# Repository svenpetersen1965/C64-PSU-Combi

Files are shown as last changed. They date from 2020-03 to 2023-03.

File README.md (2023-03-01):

# C64-PSU-Combi
A PSU for the Commodore C64 and up to two 1541-II floppy disk drives. It is based on a transformer 
for the 9VAC, which is required in a C64 and a (PCB) external power supply module, which provides
the +5V and +12V for the C64 and the 1541-II floppy disk drives. Depending on the used power supply
module, one of the 1541-II connectors can be replaced with an Amiga connection, which also requires 
-12V. This option has not been tested, since I don't have an Amiga. The PSU combi should be strong 
enough.

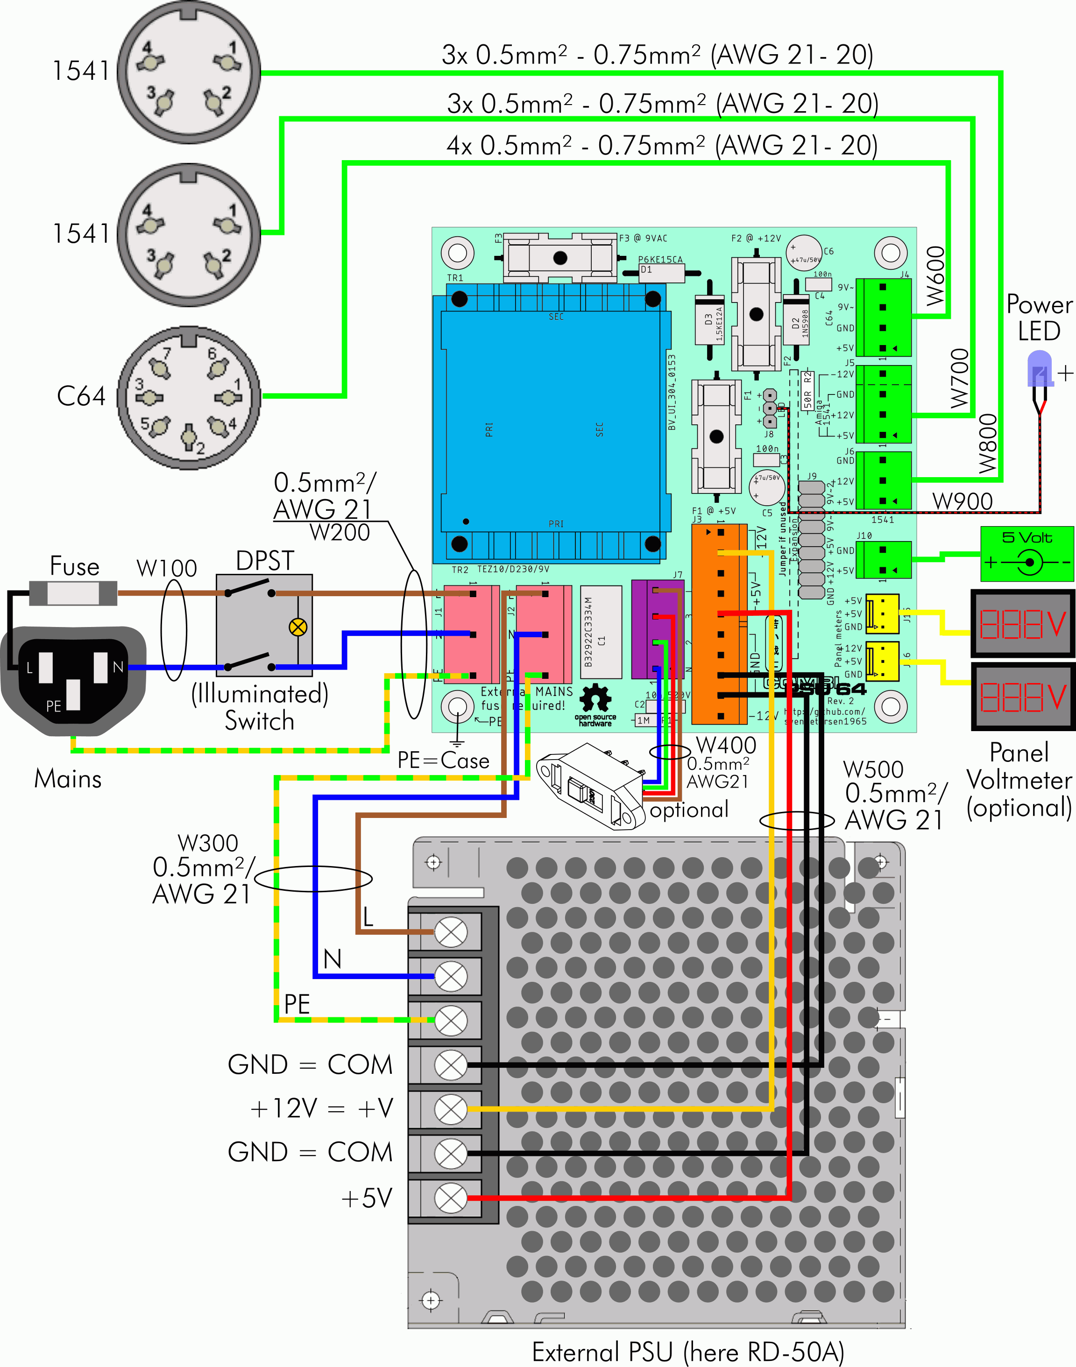
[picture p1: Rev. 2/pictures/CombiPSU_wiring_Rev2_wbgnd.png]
Block Diagram


This build is for the more experienced, since power supplies can be hazzardous and the involved 
mains voltage is potentially lethal.

Find some info on the required cable making <a href="http://tech.guitarsite.de/cable_making.html">on my website</a>

The power supply has  an open concept and can be configured to taste. It should be planned before 
parts are purchased.

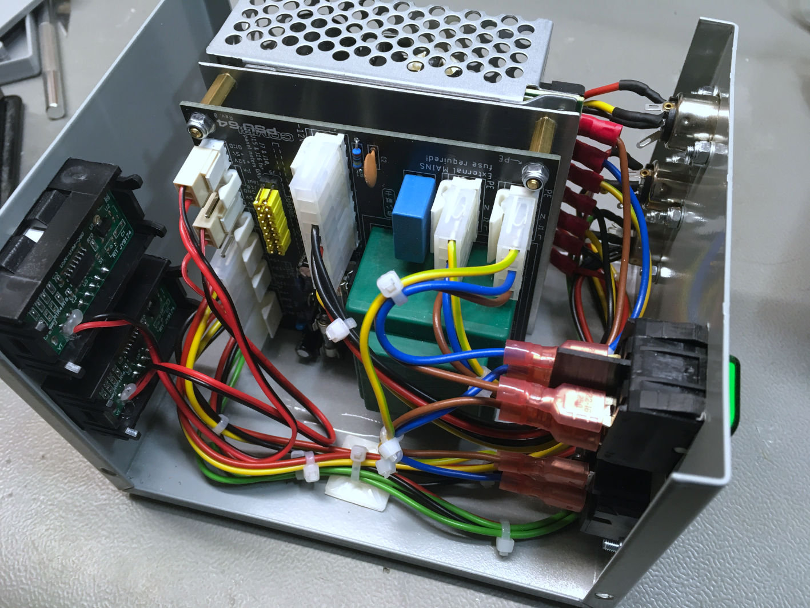
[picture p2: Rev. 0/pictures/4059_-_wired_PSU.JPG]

C64 PSU Combi in a Hammond 1411P case

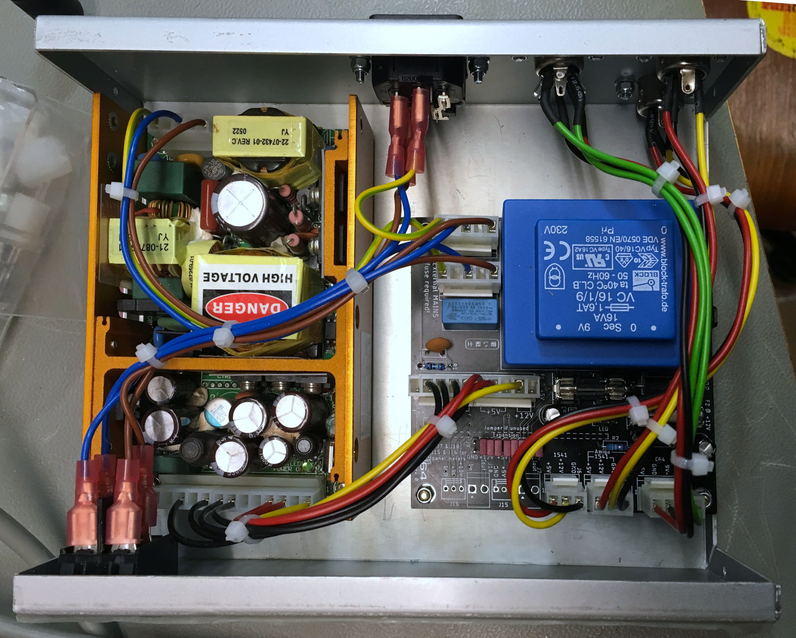
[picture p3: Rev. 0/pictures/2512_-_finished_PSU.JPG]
Finished!

C64 PSU Combi in a Teko 384 case

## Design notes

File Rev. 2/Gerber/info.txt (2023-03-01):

       
       Board: C64_PSU_Combi
       Rev.:  2
  
       Files:
       ======
  
       All Gerber files are generated in extended gerber format (RS274X)
       *.TOP        : Film top copper
       *.BOT        :  -"- bottom copper
       *.STC        :  -"- top soldermask 
       *.STS        :  -"- bottom soldermask
       *.PLC        :  -"- silk screen top
       *.PLS        :  -"- silk screen bottom
       *.DK         : Drills plated Through (Excellon)
       *.NDK        : Drills not plated Through (Excellon)
       *.OUT        : Board outline

       Board Size:
       ===========
       Length     :   98.0 mm
       Width      :   94.0 mm
       Thickness  :   1.6 mm
       Material   :   FR 4
       Copper     :   35 um
       Surface    :   HASL
       
       Remarks:
       ========
       Width >= 6mil
       Distance >= 6mil
       Drill >= 0.35mm

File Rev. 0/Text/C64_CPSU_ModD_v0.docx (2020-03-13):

C64 Combi PSU Rev. 0

Module Description

# Introduction

The C64 combi PSU is a power supply board for the Commodore C64 and up to two floppy disk drives 1541-II. Depending on the used external DC-power supply, one of the 1541 connectors can be used for a Commodore AMIGA.

This board connects to mains and it contains a 9V transformer, which provides the 9VAC for the C64. For the DC-Voltages, a variety of power supply modules can be connected externally.

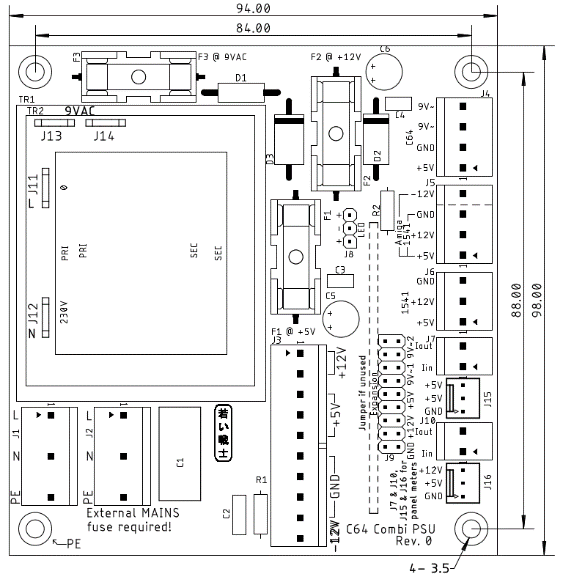
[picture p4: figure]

Figure 1: Measures of the board

The board allows a number of alternative placements and optional components:

- There are footprints for two different transformers, a chassis mount transformer can be connected via four spade connectors
- Two panel meters for +5V and +12V can be connected, if not wanted, the connectors do not need to be populated.
- An extension module can be connected, which can measure or control the output voltages
- One connector can provide voltages for either a 1541-II disk drive or an Amiga

# External Power Supply

The external power supply should either have the output voltages +5V (≥3.5A), +12 V (≥1A) for one C64 and two 1541-II floppy disk drives or +5V (≥5A), +12V (≥2A), -12V (≥0.1A). The traces on the PCB are calculated for 4A (+12V, 9VAC), 6A (+5V) and 2.5A (-12V). The fuses have to be picked according to the maximum current of the output voltages and the copper traces.

For best operation (due to voltage drops on the PBC and the cables), it is recommended to adjust the power supply to +5.1V to +5.2V. While adjustment, any devices must not be connected to the PSU. The other voltages need to be checked. A slightly higher output on +12V is also ok.

Suggested PSUs (many other possible):

- Mean Well: RD-50A (+5V @ 6A, +12V @ 2A) (e.g. Mouser: €15.34)
- Mean Well: RT-65B (+5V @ 5A, +12V @ 2.8A, -12V @ 0.5A) (e.g. Mouser: 17,43€)

# The Expansion Module

For monitoring or controlling the output voltages of the PolyPower64, an optional Expansion module can be connected to J19. The connector has input and output pins for the 9VAC, the +12V and the +5V. It also offers two GND pins.

In case the Expansion Module is not installed, the pins, mentioned before, have to be bridged with jumpers (rated 3A).

A maximum height of 20mm is assumed for the expansion module.

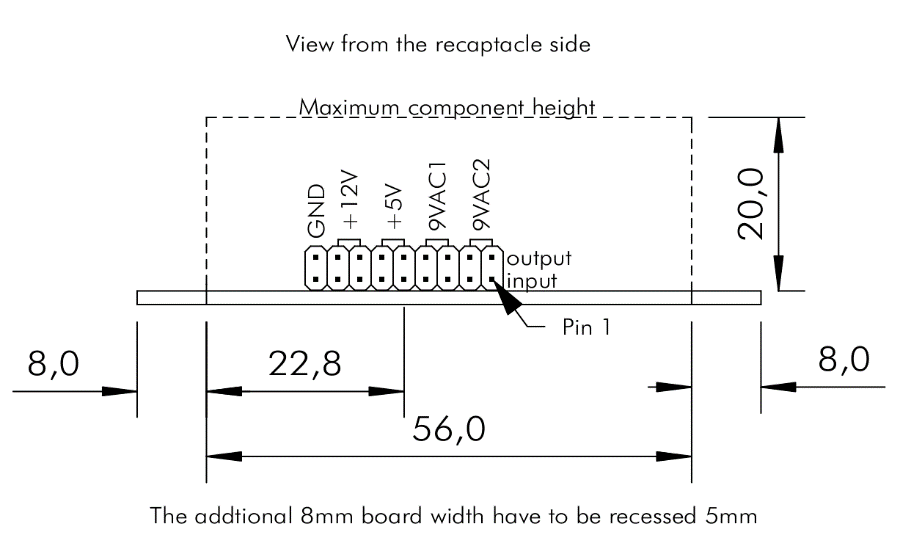
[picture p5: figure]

Figure 2: Dimensions of the Expansion Module

The maximum dimensions of the Expansion Module are shown in Figure 2. The length of the module depends on the enclosure of the power supply and the standoffs for the PCB.

Any voltage, that is unused on the expansion module should be bridged (40mil trace!) on there. The same is valid for voltages, which do not have a current measurement or any switch like function.

To prevent slipping of the connectors, the Expansion Module needs to be secured with silicon glue (which is reversible) after testing.

# Connectors

## J1, J2 – Mains connectors

- Molex KK 396 Header, Vertical, Friction Lock, 5 Circuits, Tin (Sn) Plating (Pin 2 and pin 4 removed): P/N 0026604050
- KK 3.96mm Crimp Terminal Housing, Friction Ramp, 5 Circuits, Natural: P/N 09503051
- KK 396 Crimp Terminal 2478, 18-24 AWG, Bag, Brass Tin (Sn): P/N 08500106.

Pin | Signal
1 | L (hot)
3 | N (neutral)
5 | PE (protective earth)

J1 is for the mains input, J2 is branching to the external DC-PSU.

## J3 – DC-PSU

- Molex KK 396 Header, Vertical, Friction Lock, 10 Circuits, Tin (Sn) Plating: P/N 0026604100
- KK 3.96mm Crimp Terminal Housing, Friction Ramp, 10 Circuits, Natural: P/N 09503101
- KK 396 Crimp Terminal 2478, 18-24 AWG, Bag, Brass Tin (Sn): P/N 08500106.

Pin | Signal
1 | +12V
2 | +12V
3 | +5V
4 | +5V
5 | +5V
6 | GND
7 | GND
8 | GND
9 | GND
10 | -12V

## J4 – C64 Output

- Molex KK 396 Header, Vertical, Friction Lock, 4 Circuits, Tin (Sn) Plating: P/N 0026604040
- KK 3.96mm Crimp Terminal Housing, Friction Ramp, 4 Circuits, Natural: P/N 09503041
- KK 396 Crimp Terminal 2478, 18-24 AWG, Bag, Brass Tin (Sn): P/N 08500106.

Pin | Signal
1 | +5V
2 | GND
3 | 9VAC2
4 | 9VAC1

## J5 – 1541-II or Amiga Output

### Version 1541-II

For the 1541-II only populate Pin 1-3. See J6.

### Version Amiga

- Molex KK 396 Header, Vertical, Friction Lock, 4 Circuits, Tin (Sn) Plating: P/N 0026604040
- KK 3.96mm Crimp Terminal Housing, Friction Ramp, 4 Circuits, Natural: P/N 09503041
- KK 396 Crimp Terminal 2478, 18-24 AWG, Bag, Brass Tin (Sn): P/N 08500106.

Pin | Signal
1 | +5V
2 | +12V
3 | GND
4 | -12V

## J6 – 1541-II Output

- Molex KK 396 Header, Vertical, Friction Lock, 3 Circuits, Tin (Sn) Plating: P/N 0026604030
- KK 3.96mm Crimp Terminal Housing, Friction Ramp, 3 Circuits, Natural: P/N 09503031
- KK 396 Crimp Terminal 2478, 18-24 AWG, Bag, Brass Tin (Sn): P/N 08500106.

Pin | Signal
1 | +5V
2 | +12V
3 | GND

## J7, J15 – Panel Meter (+5V)

### ~~J7 – Current path~~

The current measurement is not functional with any known Panel Meters. It will be dropped in future revisions.

- Molex KK 396 Header, Vertical, Friction Lock, 2 Circuits, Tin (Sn) Plating: P/N 0026604020
- KK 3.96mm Crimp Terminal Housing, Friction Ramp, 2 Circuits, Natural: P/N 09503021
- KK 396 Crimp Terminal 2478, 18-24 AWG, Bag, Brass Tin (Sn): P/N 08500106.

Pin | Signal
1 | Current in (+)
2 | Current out (-)

### J15 – Voltage connection

- Molex KK 254 Wire-to-Board Header, Vertical, with Friction Lock, 3 Circuits, Tin (Sn) Plating: P/N 22272031
- KK 254 Crimp Housing, 3 Circuits, Natural: P/N 22-01-3037
- KK 254 Crimp Terminal, 22-30 AWG, Bag, Hot Tin (Sn) Dip Plating: P/N 08500114

Pin | Signal
1 | GND
2 | +5V (supply)
3 | +5V (measurement)

## J10, J16 – Panel Meter (+12V)

### ~~J~~~~10~~ ~~– Current path~~

The current measurement is not functional with any known Panel Meters. It will be dropped in future revisions.

- Molex KK 396 Header, Vertical, Friction Lock, 2 Circuits, Tin (Sn) Plating: P/N 0026604020
- KK 3.96mm Crimp Terminal Housing, Friction Ramp, 2 Circuits, Natural: P/N 09503021
- KK 396 Crimp Terminal 2478, 18-24 AWG, Bag, Brass Tin (Sn): P/N 08500106.

Pin | Signal
1 | Current in (+)
2 | Current out (-)

### J16 – Voltage connection

- Molex KK 254 Wire-to-Board Header, Vertical, with Friction Lock, 3 Circuits, Tin (Sn) Plating: P/N 22272031
- KK 254 Crimp Housing, 3 Circuits, Natural: P/N 22012031
- KK 254 Crimp Terminal, 22-30 AWG, Bag, Hot Tin (Sn) Dip Plating: P/N 08500114

Pin | Signal
1 | GND
2 | +5V (supply)
3 | +12V (measurement)

## J11-J14 – Chassis Mount Transformer Connectors

In case it is desired to use a chassis mount transformer instead of the PCB mount types (TR1 or TR2), some spade connectors (6.3 x 0.8) can be placed. It is recommended to use fully isolated FastOn connectors on the cables.

Connector | Signal
J11 | Mains L (hot)
J12 | Mains N (neutral)
J13 | 9VAC (2)
J14 | 9VAC (1)

## Expansion connector – J19

- Pin header, 2 x 9 circuits, 2.54mm pitch (0.1”)
- Jumper from input to output if not used (jumpers rated 3A)

Signal | Pin | Pin | Signal
Input 9VAC (2) | 1 | 2 | Output 9VAC (2)
Input 9VAC (2) | 3 | 4 | Output 9VAC (2)
Input 9VAC (1) | 5 | 6 | Output 9VAC (1)
Input 9VAC (1) | 7 | 8 | Output 9VAC (1)
Input +5V | 9 | 10 | Output +5V
Input +5V | 11 | 12 | Output +5V
Input +12V | 13 | 14 | Output +12V
Input +12V | 15 | 16 | Output +12V
GND | 17 | 18 | GND

If no expansion module is in place, the inputs have to be connected to the corresponding outputs with jumpers (2.54mm, 0.1”).

## Power LED – J8

- Pin header, 1x3 circuits, 2.54mm (0.1”) pitch
- Crimp housing: Dupont crimp housing
- Dupont crimp terminals

It is possible to use a widely available (Ebay, AliExpress etc.) Dupont cable, which can be cut and soldered to the LED.

Pin | Signal
1 | LED +
2 | LED -
3 | LED +

## PE connection

The marked mounting hole is connected to PE.

# Fuses

Since the rating of the fuses depend on the external power supply, that is used, there can only be recommendations. The copper traces on the PCB are rated for 4A (9VAC, +12V) and 6A (+5V). These are the absolute maximum ratings for the fuses. Do not exceed this, even if the power supply is rated higher!

Fuse | Voltage | Recommendation
F1 | +5V | 3A
F2 | +12V | 1.6A
F3 | 9VAC | 1.6A

The ratings above are conservative. For powering an Amiga, higher ratings are required. Refer to the ratings of the original power supply.

The (external) mains fuse depends on the inrush current of the external power supply. The value has to be determined carefully. In case this fuse fails, the rating has to be increased.

# Wiring

This device is connected to mains. Mains voltage is potentially lethal. High currents, that can occur in this device can cause fire hazards. Do not carry out this work, if you are not trained!

Up to four sorts of crimp contacts are required for installing this device:

- FastOn Flat connectors 6.3 x 0.8 (isolated, red) for mains connector/switch
- Fork shaped/ring cable lugs (semi isolated, red) for the power supply
- Molex SPOX/KK 3.96
- Molex KK2.54

The crimp tools for the first two types are cheap. A tool capable of isolated crimps is required. At least the 2nd type has to be crimped, while the first type can be soldered (do not forget the shrinkable sleeve). Crimping is the recommended method.

The latter two contact types can be crimped with the Engineer PA-20 or (probably) the IWISS IWS-2820M. The cables can also be directly solder into the pads of the connectors. This is possible, but not recommended.

A quality control of every crimp is required. That means, the flat connectors and the ring cable lugs must not fall off the cable when pulling it.

It is definitely recommended to order more than just the required amount of each crimp connector/terminal. It is not unlikely, that some crimps don’t work out, depending on the experience with this production method.

The installation of the PSU in a metal enclosure requires connection to PE of all metal parts of this enclosure. These connections need to be proved (at least with a multimeter) after finishing the assembly. One mounting hole of the PCB is connected to the PE of the installation. This is marked “← PE”. Chopper disks are recommended to attain a good connection.

Many metal cases can be used as suitable enclosure for this PSU.

The Hammond 1411P was used for one version of the PSU Combi. It is quite compact (127mm x 152mm x 102mm) and fits the RD-50A. The price is about 16€ (tme.eu/2020).

Another case is the TEKO 384 (203mm x 160mm x 70mm). It is less high, both, the external PSU and the PCB can be mounted flat, which might be easier. The price is about 22€ (reichelt.de/2020).

C64 Power Jack | Pin | Voltage
| 1 | -
| 2 | GND
| 3 | -
| 4 | -
| 5 | +5V
| 6 | 9VAC(1)
| 7 | 9VAC(2)

Table 1: Power jack of the C64

In case, the power cables should stay connected to this PSU, strain reliefs are required. The recommended way is a DIN-jack on the back panel of the power supply and extra cables to have as few cables in the installation as possible.

1541 Power Jack | Pin | Voltage
| 1 | +5V
| 2 | GND
| 3 | -
| 4 | +12V

Table 2: Power jack of the 1541-II

Table 1 and Table 2 show the power jacks of the C64 and the 1541-II. The view is on the particular contact side. This is identical with the view on the solder side of the respective DIN plugs. The cables soldered to the din plugs should be 0.5mm²/AWG21. It is possible to use 0.75mm²/AWG20 wires, but this might require to clip off some of the wire strands, since the solder cups of the DIN plugs are usually not capable of accepting a wire of this diameter.

After finishing the wiring, it is required to test the complete device. Swapping the voltages by confusing the pins or the wiring will usually damage the connected devices. The +5V should measure between +4.9V and +5.2V. The 9VAC are not regulated and might be quite a bit higher without load. 11VAC are still an acceptable reading.

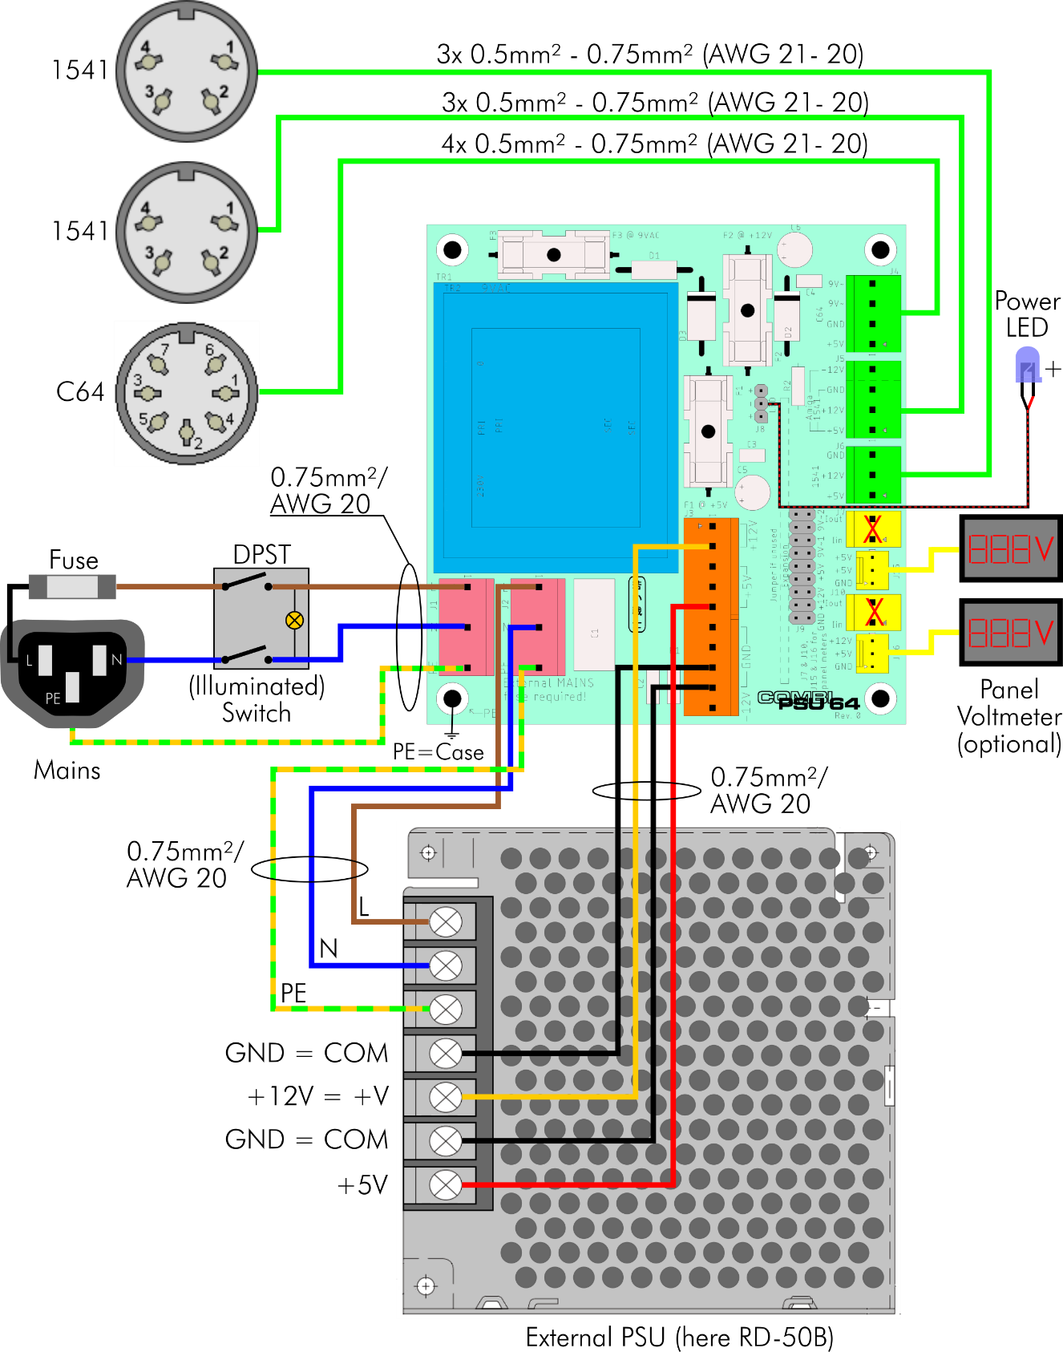
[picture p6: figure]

Figure 3: Wiring of the CombiPSU64

A proper PE (protective earth) installation is mandatory. The PE cables should be slightly longer than the L (life/hot) and N (neutral) wires. The purpose is, that in case of mechanical stress, the PE cables are pulled off last.

# Picture gallery

Figure 4 shows two versions of the PSU Combi. Two different external power supplies are used. Left is an XPower open frame PSU, which was used, because it was “in stock”. The right power supply is the Mean Well RD-50A. The both boards are assembled with the different transformer types.

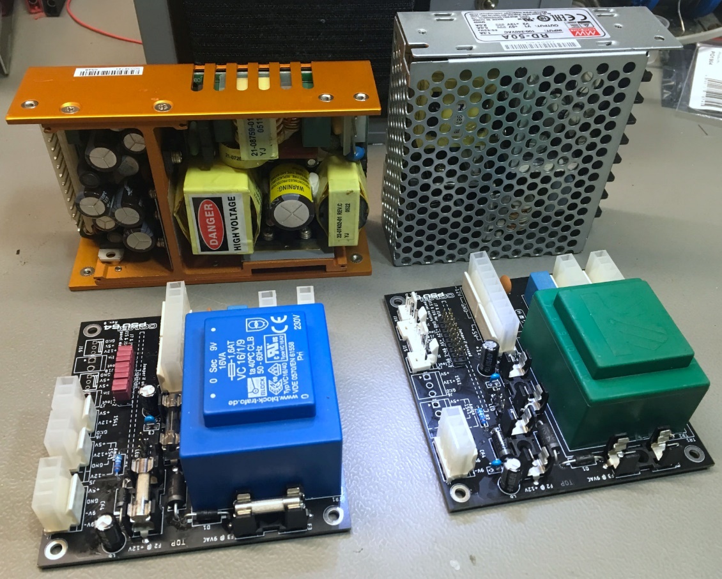
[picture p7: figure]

Figure 4: two versions of the PSU Combi

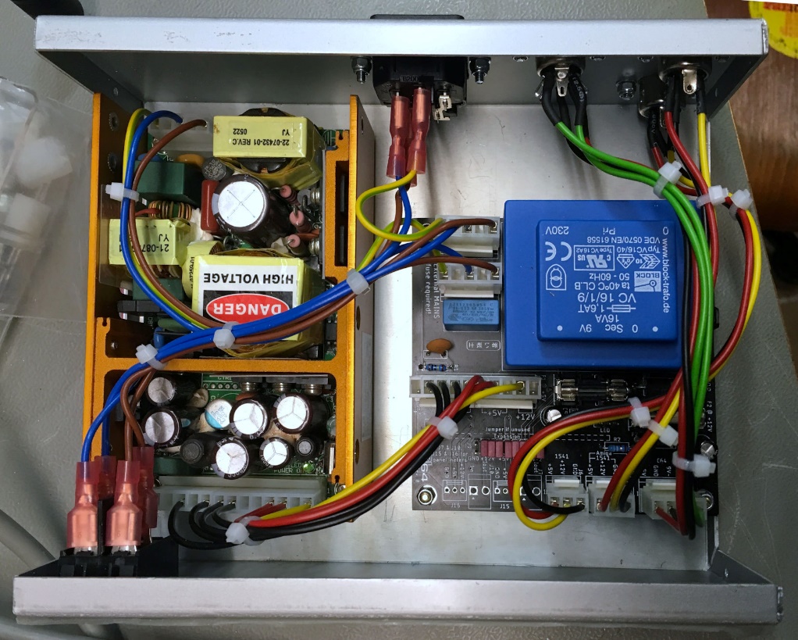
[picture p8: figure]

Figure 5: Finished PSU in TEKO 384 case

Figure 5 shows the finished PSU in the TEKO 384 case. The mains switch is on the front. The external PSU and the PCB fit side by side. The PSU can be mounted directly on the bottom of the case, while the PCB sits on 10mm hex bolts. The wiring of the mains and the output jacks require some space, due to the flat connectors and the bending radius of the cables.


Figure 6: Finished PSU in the Hammond 1411P case

Figure 6 shows the PSU mounted inside the Hammond 1411P case. The RD-50A is mounted upright. The PCB is attached to a fitting panel, which is screwed to the bottom of the PSU and a mounting angle. This is the most compact configuration.

Cable ties and adhesive cable posts provide a clean cable routing. The mains switch is on the back.

Two panel voltmeters are installed. This is not a requirement. The voltmeter should be calibrated with a multimeter to get a useful accuracy.

Figure 7 shows the power jacks mounted to the back panel and the connection to the RD-50A with cable lugs.

Figure 8 shows the back side of the Hammond 1411P case. The mains switch is in the back, the output cables are also in the back. The output cables are detachable, which is a nice feature in case not all outputs are used permanently. In case one or two cables should stay permanently attached, strain reliefs can be mounted on the back panel.

Figure 9 shows the mounting of the RD-50A power supply and the PCB in the Hammond case. The PCB sits on a fitting panel via 15mm hex bolts. The fitting panel is screwed to the bottom of the RD-50A. A 10mm x 10mm aluminum mounting angle is screwed to the fitting panel and mounted to the bottom of the case to provide more stability.

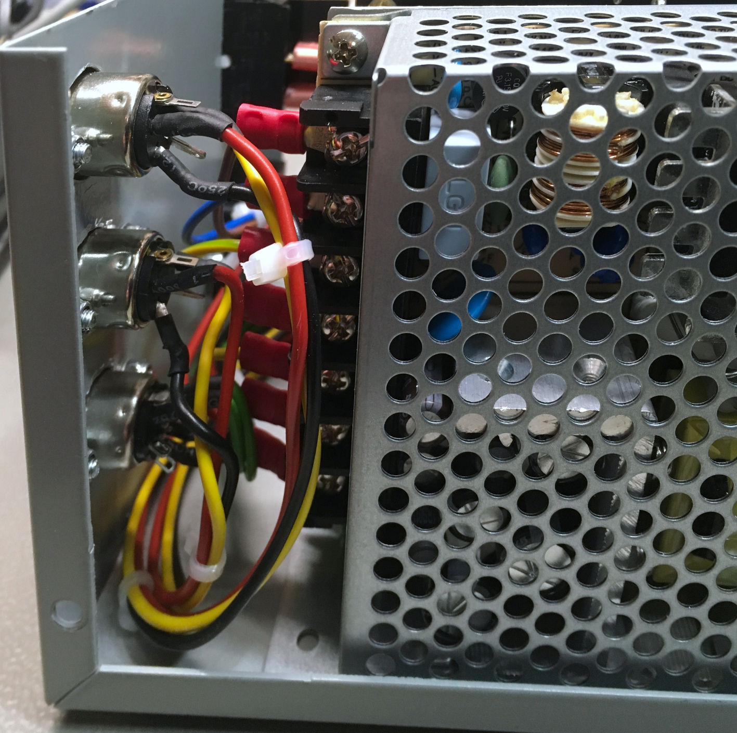
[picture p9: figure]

Figure 7: Power jacks and cables to the RD-50A

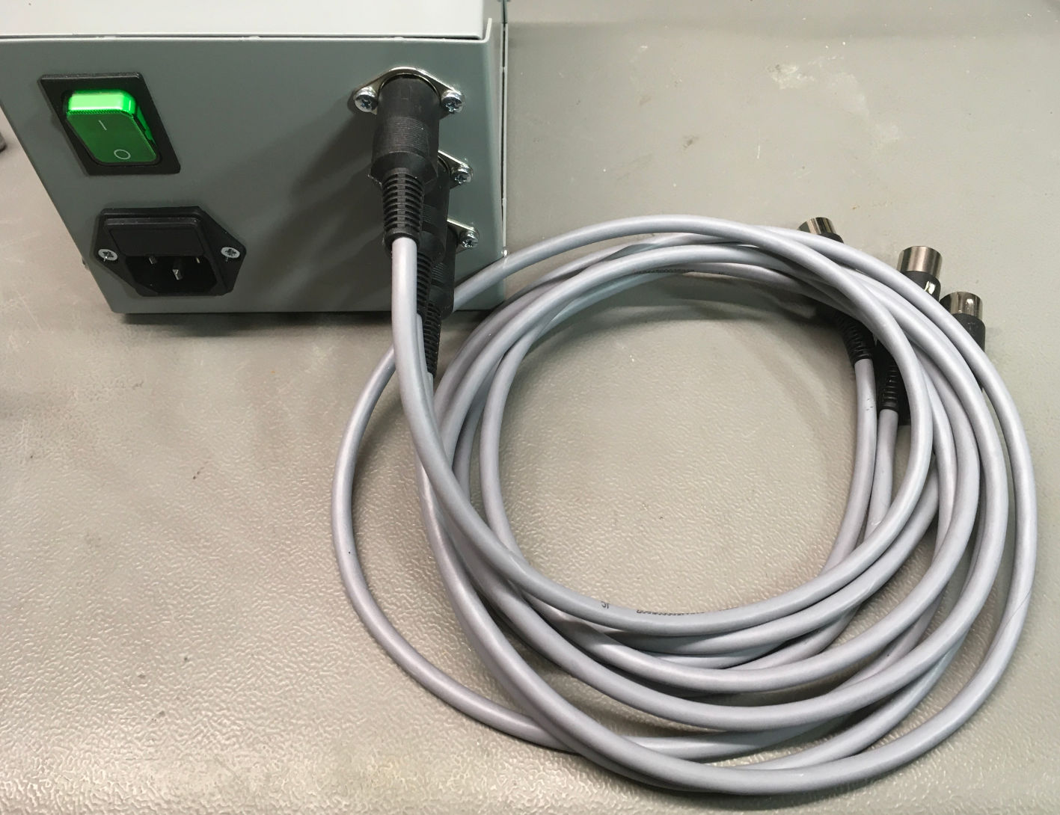
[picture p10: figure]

Figure 8: Back side of the Hammond case and output cables

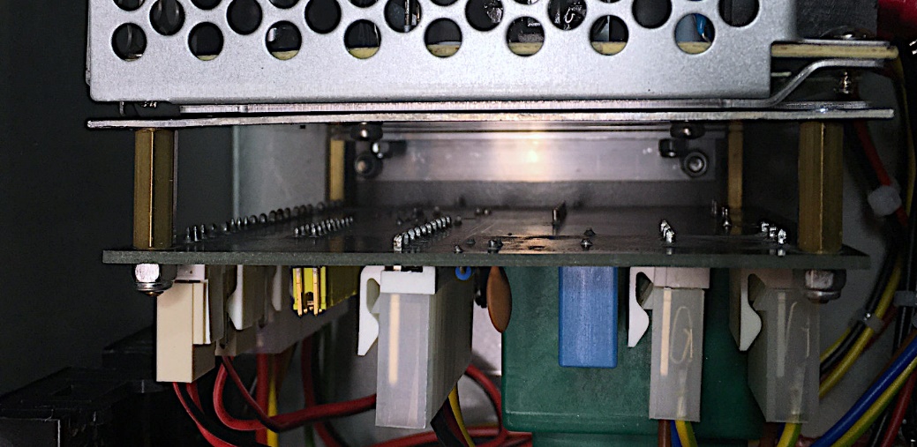
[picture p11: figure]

Figure 9: Mounting of the RD-50A and the PCB in the Hammond Case

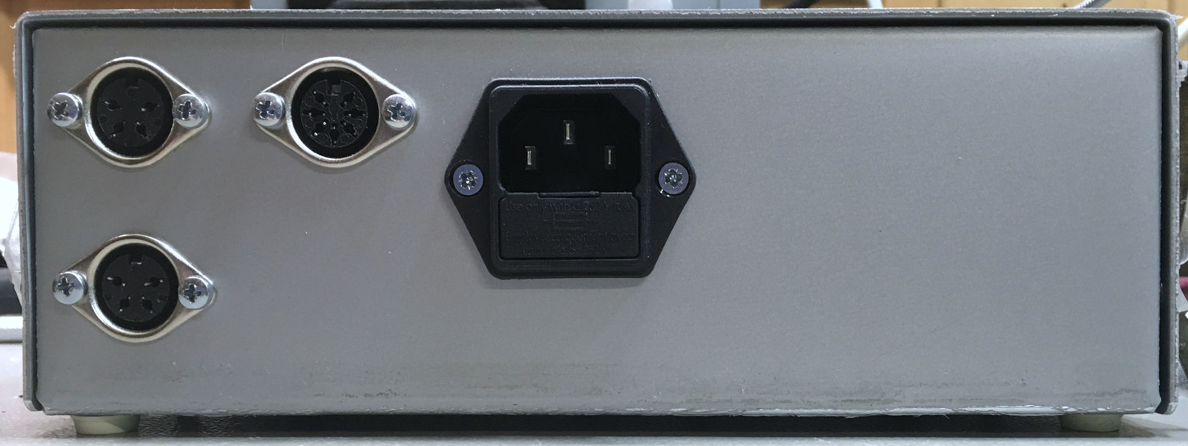
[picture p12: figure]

Figure 10: Back of the Teko 384 case

Figure 10 shows the back of the Teko case 384. The (illuminated) mains switch is in the front and also serves as a power indicator.

# Further thoughts

The panel meters are not really required. In case, they are not used, the 5V on the voltage connector of the panel meter can be connected to a USB A jack, which then can power accessories like the RetroTINK video converter. This way, one more power supply can be saved. It was not tested to drive a PI1541 with it, which might require a bit more current.

Since many possible externals PSUs have a wide range input – the RD-50A is capable of 88VAC to 264VAC – the Rev. 1 of the PSU Combi will have an option for a transformer that allows 115V/230V switching.

# Testing

After finishing the power supply, it is very important to test the pinning of the output jacks/cables. A mistake could fry the connected device.

The ratings of the power supply depend on the used components. This way, the mains fuse requires to be determined. Values of 500mA to maybe 1A should be tested. The PSU combi does have an inrush current, so if the fuse is too weak, it will blow frequently. Nevertheless, the fuse should be as weak as possible.

C64_CPSU_ModD_v0.docx 13.03.2020 20:18 Drafted by Sven Petersen Page 2 of 2 Doc.-No.: 131-6-01-00

C64_CPSU_ModD_v0.docx 13.03.2020 20:18 Drafted by Sven Petersen Page 1 of 1 Doc.-No.: 131-6-01-00

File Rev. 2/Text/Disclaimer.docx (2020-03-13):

Disclaimer

Working with mains voltages can be harmful and cause death. Do not connect this PCB to mains (230VAC) unless you are trained/authorized in doing so and know the required safety regulations.

An electrical shock can be deadly. Improper installations can lead to fire hazards.

This PSU is a prototype, it is not certified in any way and might only be used as a prototype under laboratory conditions. Usage is at own risk.

The PSU is designed to be installed in a metal enclosure. A 3 prong mains connector is required and the case has to be connected to PE in a suitable way. A sufficient ventilation of the enclosure is required.

The mains fuse is not included on the PCB. A suitable fuse has to be installed in the mains circuitry externally.

The documentation is drafted to the best of my knowledge. The creator is not liable for the accuracy and completeness.

Disclaimer.docx 30.07.2019 14:04 Erstellt von Sven Petersen Seite 2 von 2 Dok.-Nr.: 000-8-00-00

Disclaimer.docx 30.07.2019 14:04 Drafted by Sven Petersen Page 1 of 1

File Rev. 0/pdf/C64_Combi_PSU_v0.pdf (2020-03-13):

# Project Documentation

## C64 Combi PSU

## Project number: 131

## Revision: 0

## Date: 28.07.2019

Disclaimer.docx | 13.03.2020 20:42
Drafted by Sven Petersen | Page 1 of 1

### Disclaimer

Working with mains voltages can be harmful and cause death. Do not connect this PCB to mains (230VAC) unless you are trained/authorized in doing so and know the required safety regulations.

An electrical shock can be deadly. Improper installations can lead to fire hazards.

This PSU is a prototype, it is not certified in any way and might only be used as a prototype under laboratory conditions. Usage is at own risk.

The PSU is designed to be installed in a metal enclosure. A 3 prong mains connector is required and the case has to be connected to PE in a suitable way. A sufficient ventilation of the enclosure is required.

The mains fuse is not included on the PCB. A suitable fuse has to be installed in the mains circuitry externally.

The documentation is drafted to the best of my knowledge. The creator is not liable for the accuracy and completeness.

C64_CPSU_ModD_v0.docx | | 13.03.2020 20:18
Drafted by Sven Petersen | Page 1 of 13 | Doc.-No.: 131-6-01-00

### C64 Combi PSU Rev. 0

### Module Description

Table of Contents

## Introduction

The C64 combi PSU is a power supply board for the Commodore C64 and up to two floppy disk drives 1541-II. Depending on the used external DC-power supply, one of the 1541 connectors can be used for a Commodore AMIGA.

This board connects to mains and it contains a 9V transformer, which provides the 9VAC for the C64. For the DC-Voltages, a variety of power supply modules can be connected externally.

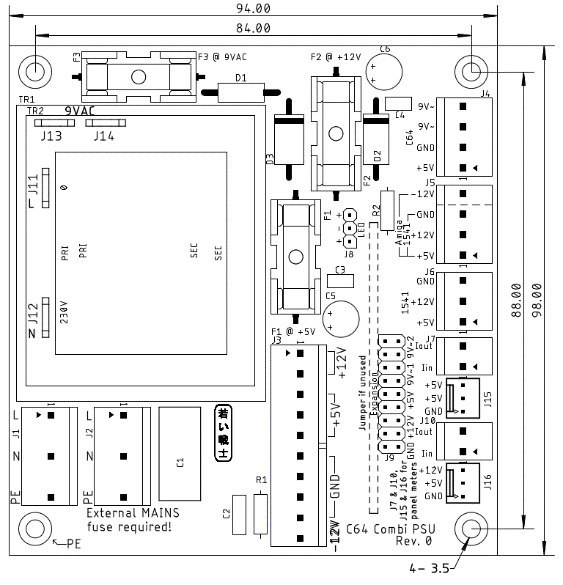
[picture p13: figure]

Drafted by Sven Petersen | Page 2 of 13 | Doc.-No.: 131-6-01-00

Figure 1: Measures of the board

The board allows a number of alternative placements and optional components:

- There are footprints for two different transformers, a chassis mount transformer can be connected via four spade connectors
- Two panel meters for +5V and +12V can be connected, if not wanted, the connectors do not need to be populated.
- An extension module can be connected, which can measure or control the output voltages
- One connector can provide voltages for either a 1541-II disk drive or an Amiga

## External Power Supply

The external power supply should either have the output voltages +5V (≥3.5A), +12 V (≥1A) for one C64 and two 1541-II floppy disk drives or +5V (≥5A), +12V (≥2A), -12V (≥0.1A). The traces on the PCB are calculated for 4A (+12V, 9VAC), 6A (+5V) and 2.5A (-12V). The fuses have to be picked according to the maximum current of the output voltages and the copper traces.

For best operation (due to voltage drops on the PBC and the cables), it is recommended to adjust the power supply to +5.1V to +5.2V. While adjustment, any devices must not be connected to the PSU. The other voltages need to be checked. A slightly higher output on +12V is also ok.

Suggested PSUs (many other possible):

- Mean Well: RD-50A (+5V @ 6A, +12V @ 2A) (e.g. Mouser: €15.34)
- Mean Well: RT-65B (+5V @ 5A, +12V @ 2.8A, -12V @ 0.5A) (e.g. Mouser: 17,43€)

## The Expansion Module

For monitoring or controlling the output voltages of the PolyPower64, an optional Expansion module can be connected to J19. The connector has input and output pins for the 9VAC, the +12V and the +5V. It also offers two GND pins.

In case the Expansion Module is not installed, the pins, mentioned before, have to be bridged with jumpers (rated 3A).

A maximum height of 20mm is assumed for the expansion module.


Drafted by Sven Petersen | Page 3 of 13 | Doc.-No.: 131-6-01-00

Figure 2: Dimensions of the Expansion Module

The maximum dimensions of the Expansion Module are shown in Figure 2. The length of the module depends on the enclosure of the power supply and the standoffs for the PCB.

Any voltage, that is unused on the expansion module should be bridged (40mil trace!) on there. The same is valid for voltages, which do not have a current measurement or any switch like function.

To prevent slipping of the connectors, the Expansion Module needs to be secured with silicon glue (which is reversible) after testing.

## Connectors

### J1, J2 – Mains connectors

- Molex KK 396 Header, Vertical, Friction Lock, 5 Circuits, Tin (Sn) Plating (Pin 2 and pin 4 removed): P/N 0026604050
- KK 3.96mm Crimp Terminal Housing, Friction Ramp, 5 Circuits, Natural: P/N 09503051
- KK 396 Crimp Terminal 2478, 18-24 AWG, Bag, Brass Tin (Sn): P/N 08500106.

Pin Signal
1 L (hot)
3 N (neutral)
5 PE (protective earth)

J1 is for the mains input, J2 is branching to the external DC-PSU.

### J3 – DC-PSU

- Molex KK 396 Header, Vertical, Friction Lock, 10 Circuits, Tin (Sn) Plating:
P/N 0026604100
- KK 3.96mm Crimp Terminal Housing, Friction Ramp, 10 Circuits, Natural: P/N 09503101
- KK 396 Crimp Terminal 2478, 18-24 AWG, Bag, Brass Tin (Sn): P/N 08500106.

Drafted by Sven Petersen | Page 4 of 13 | Doc.-No.: 131-6-01-00
Pin | Signal
1 +12V
2 +12V
3 +5V
4 +5V
5 +5V
6 GND
7 GND
8 GND
9 GND
10 -12V

### J4 – C64 Output

- Molex KK 396 Header, Vertical, Friction Lock, 4 Circuits, Tin (Sn) Plating:
P/N 0026604040
- KK 3.96mm Crimp Terminal Housing, Friction Ramp, 4 Circuits, Natural: P/N 09503041
- KK 396 Crimp Terminal 2478, 18-24 AWG, Bag, Brass Tin (Sn): P/N 08500106.

Pin Signal
1 +5V
2 GND
3 9VAC2
4 9VAC1

### J5 – 1541-II or Amiga Output

Version 1541-II
For the 1541-II only populate Pin 1-3. See J6.

Version Amiga
- Molex KK 396 Header, Vertical, Friction Lock, 4 Circuits, Tin (Sn) Plating:
P/N 0026604040
- KK 3.96mm Crimp Terminal Housing, Friction Ramp, 4 Circuits, Natural: P/N 09503041
- KK 396 Crimp Terminal 2478, 18-24 AWG, Bag, Brass Tin (Sn): P/N 08500106.

Pin Signal
1 +5V
2 +12V
3 GND
4 -12V

### J6 – 1541-II Output

- Molex KK 396 Header, Vertical, Friction Lock, 3 Circuits, Tin (Sn) Plating:
P/N 0026604030
- KK 3.96mm Crimp Terminal Housing, Friction Ramp, 3 Circuits, Natural: P/N 09503031
- KK 396 Crimp Terminal 2478, 18-24 AWG, Bag, Brass Tin (Sn): P/N 08500106.
•

Drafted by Sven Petersen | Page 5 of 13 | Doc.-No.: 131-6-01-00
Pin | Signal
1 +5V
2 +12V
3 GND

### J7, J15 – Panel Meter (+5V)

J7 – Current path
The current measurement is not functional with any known Panel Meters. It will be dropped in future revisions.
- Molex KK 396 Header, Vertical, Friction Lock, 2 Circuits, Tin (Sn) Plating:
P/N 0026604020
- KK 3.96mm Crimp Terminal Housing, Friction Ramp, 2 Circuits, Natural: P/N 09503021
- KK 396 Crimp Terminal 2478, 18-24 AWG, Bag, Brass Tin (Sn): P/N 08500106.

Pin Signal
1 Current in (+)
2 Current out (-)
J15 – Voltage connection
- Molex KK 254 Wire-to-Board Header, Vertical, with Friction Lock, 3 Circuits, Tin (Sn) Plating: P/N 22272031
- KK 254 Crimp Housing, 3 Circuits, Natural: P/N 22-01-3037
- KK 254 Crimp Terminal, 22-30 AWG, Bag, Hot Tin (Sn) Dip Plating: P/N 08500114

Pin Signal
1 GND
2 +5V (supply)
3 +5V (measurement)

### J10, J16 – Panel Meter (+12V)

J10 – Current path
The current measurement is not functional with any known Panel Meters. It will be dropped in future revisions.
- Molex KK 396 Header, Vertical, Friction Lock, 2 Circuits, Tin (Sn) Plating:
P/N 0026604020
- KK 3.96mm Crimp Terminal Housing, Friction Ramp, 2 Circuits, Natural: P/N 09503021
- KK 396 Crimp Terminal 2478, 18-24 AWG, Bag, Brass Tin (Sn): P/N 08500106.

Pin Signal
1 Current in (+)
2 Current out (-)
J16 – Voltage connection
- Molex KK 254 Wire-to-Board Header, Vertical, with Friction Lock, 3 Circuits, Tin (Sn) Plating: P/N 22272031
- KK 254 Crimp Housing, 3 Circuits, Natural: P/N 22012031
- KK 254 Crimp Terminal, 22-30 AWG, Bag, Hot Tin (Sn) Dip Plating: P/N 08500114

Drafted by Sven Petersen | Page 6 of 13 | Doc.-No.: 131-6-01-00
Pin | Signal
1 GND
2 +5V (supply)
3 +12V (measurement)

### J11-J14 – Chassis Mount Transformer Connectors

In case it is desired to use a chassis mount transformer instead of the PCB mount types (TR1 or TR2), some spade connectors (6.3 x 0.8) can be placed. It is recommended to use fully isolated FastOn connectors on the cables.

Connector Signal
J11 | Mains L (hot)
J12 | Mains N (neutral)
J13 | 9VAC (2)
J14 | 9VAC (1)

### Expansion connector – J19

- Pin header, 2 x 9 circuits, 2.54mm pitch (0.1”)
- Jumper from input to output if not used (jumpers rated 3A)
Signal Pin | Pin Signal
Input 9VAC (2) | 1 | 2 | Output 9VAC (2)
Input 9VAC (2) | 3 | 4 | Output 9VAC (2)
Input 9VAC (1) | 5 | 6 | Output 9VAC (1)
Input 9VAC (1) | 7 | 8 | Output 9VAC (1)
Input +5V | 9 | 10 | Output +5V
Input +5V | 11 | 12 | Output +5V
Input +12V | 13 | 14 | Output +12V
Input +12V | 15 | 16 | Output +12V
GND | 17 | 18 | GND

If no expansion module is in place, the inputs have to be connected to the corresponding outputs
with jumpers (2.54mm, 0.1”).

### Power LED – J8 - Pin header, 1x3 circuits, 2.54mm (0.1”) pitch

- Crimp housing: Dupont crimp housing
- Dupont crimp terminals

It is possible to use a widely available (Ebay, AliExpress etc.) Dupont cable, which can be cut and soldered to the LED.

Pin Signal
1 LED +
2 LED -
3 LED +

Drafted by Sven Petersen | Page 7 of 13 | Doc.-No.: 131-6-01-00

### PE connection

The marked mounting hole is connected to PE.

## Fuses

Since the rating of the fuses depend on the external power supply, that is used, there can only be recommendations. The copper traces on the PCB are rated for 4A (9VAC, +12V) and 6A (+5V). These are the absolute maximum ratings for the fuses. Do not exceed this, even if the power supply is rated higher!

Fuse | Voltage | Recommendation
F1 | +5V | 3A
F2 | +12V | 1.6A
F3 | 9VAC | 1.6A

The ratings above are conservative. For powering an Amiga, higher ratings are required. Refer to the ratings of the original power supply.

The (external) mains fuse depends on the inrush current of the external power supply. The value has to be determined carefully. In case this fuse fails, the rating has to be increased.

## Wiring

This device is connected to mains. Mains voltage is potentially lethal. High currents, that can occur in this device can cause fire hazards. Do not carry out this work, if you are not trained!

Up to four sorts of crimp contacts are required for installing this device:

- FastOn Flat connectors 6.3 x 0.8 (isolated, red) for mains connector/switch
- Fork shaped/ring cable lugs (semi isolated, red) for the power supply
- Molex SPOX/KK 3.96
- Molex KK2.54

The crimp tools for the first two types are cheap. A tool capable of isolated crimps is required. At least the 2nd type has to be crimped, while the first type can be soldered (do not forget the shrinkable sleeve). Crimping is the recommended method.

The latter two contact types can be crimped with the Engineer PA-20 or (probably) the IWISS IWS-2820M. The cables can also be directly solder into the pads of the connectors. This is possible, but not recommended.

A quality control of every crimp is required. That means, the flat connectors and the ring cable lugs must not fall off the cable when pulling it.

It is definitely recommended to order more than just the required amount of each crimp connector/terminal. It is not unlikely, that some crimps don’t work out, depending on the experience with this production method.

The installation of the PSU in a metal enclosure requires connection to PE of all metal parts of this enclosure. These connections need to be proved (at least with a multimeter) after finishing the assembly. One mounting hole of the PCB is connected to the PE of the installation. This is marked
“← PE”. Chopper disks are recommended to attain a good connection.

Many metal cases can be used as suitable enclosure for this PSU.

Drafted by Sven Petersen | Page 8 of 13 | Doc.-No.: 131-6-01-00

The Hammond 1411P was used for one version of the PSU Combi. It is quite compact (127mm x 152mm x 102mm) and fits the RD-50A. The price is about 16€ (tme.eu/2020).

Another case is the TEKO 384 (203mm x 160mm x 70mm). It is less high, both, the external PSU

### and the PCB can be mounted flat, which might be easier. The price is about 22€

(reichelt.de/2020).

C64 Power Jack | Pin | Voltage
1 -
2 GND
3 -
4 -
5 +5V
6 9VAC(1)
7 9VAC(2)
Table 1: Power jack of the C64

In case, the power cables should stay connected to this PSU, strain reliefs are required. The recommended way is a DIN-jack on the back panel of the power supply and extra cables to have as few cables in the installation as possible.

1541 Power Jack | Pin | Voltage
1 +5V
2 GND
3 -
4 +12V

Table 2: Power jack of the 1541-II

Table 1 and Table 2 show the power jacks of the C64 and the 1541-II. The view is on the particular contact side. This is identical with the view on the solder side of the respective DIN plugs. The cables soldered to the din plugs should be 0.5mm²/AWG21. It is possible to use 0.75mm²/AWG20 wires, but this might require to clip off some of the wire strands, since the solder cups of the DIN plugs are usually not capable of accepting a wire of this diameter.

After finishing the wiring, it is required to test the complete device. Swapping the voltages by confusing the pins or the wiring will usually damage the connected devices. The +5V should measure between +4.9V and +5.2V. The 9VAC are not regulated and might be quite a bit higher without load. 11VAC are still an acceptable reading.

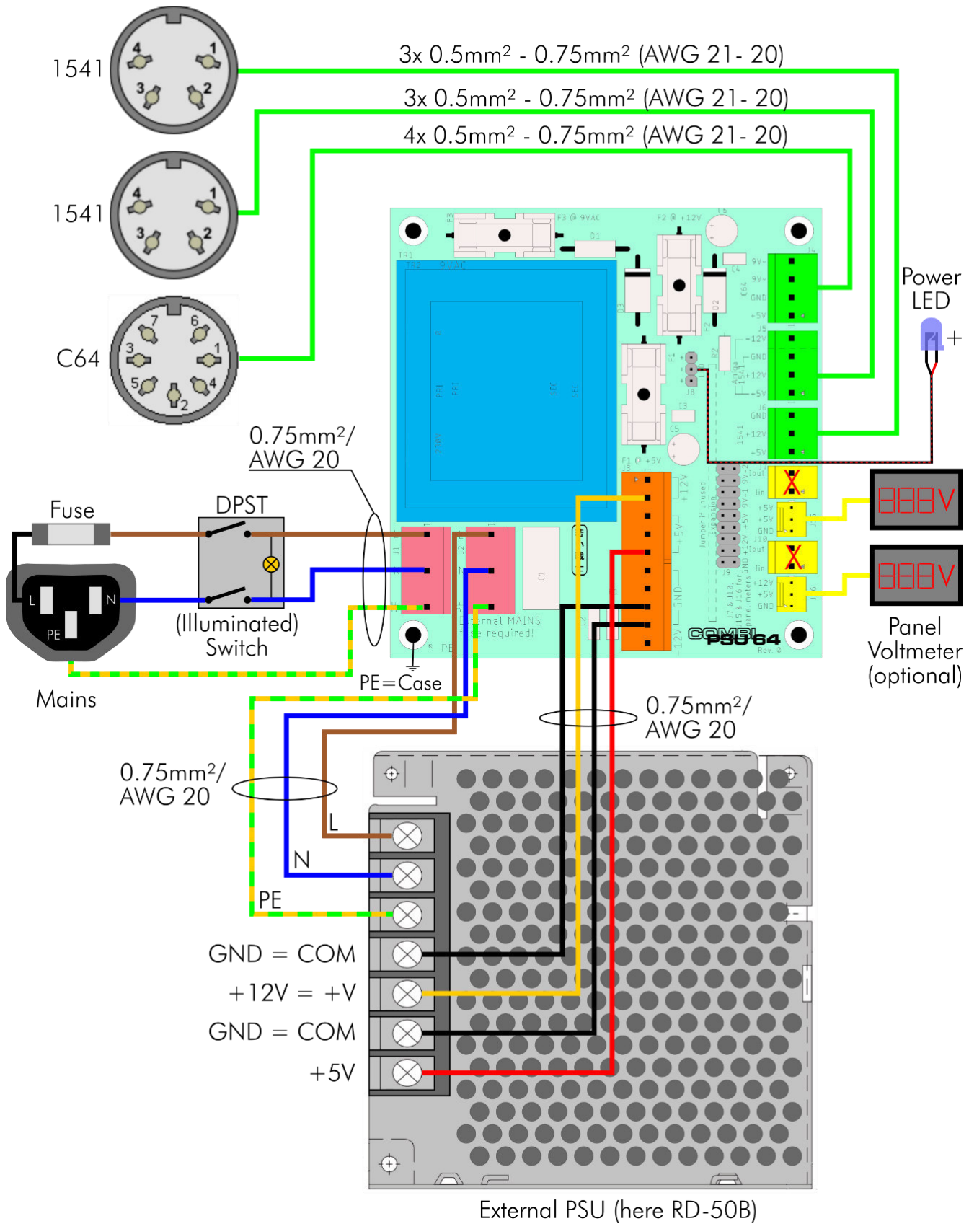
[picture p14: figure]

Drafted by Sven Petersen | Page 9 of 13 | Doc.-No.: 131-6-01-00

Figure 3: Wiring of the CombiPSU64

A proper PE (protective earth) installation is mandatory. The PE cables should be slightly longer than the L (life/hot) and N (neutral) wires. The purpose is, that in case of mechanical stress, the PE cables are pulled off last.

## Picture gallery

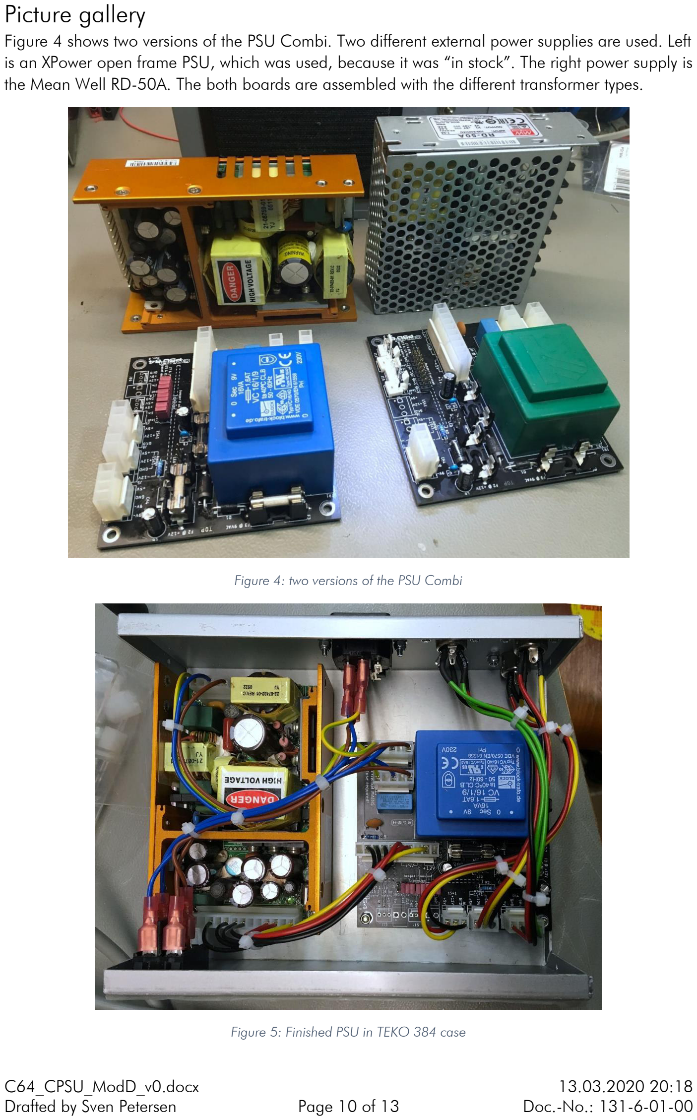
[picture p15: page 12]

Drafted by Sven Petersen | Page 10 of 13 | Doc.-No.: 131-6-01-00

Figure 4 shows two versions of the PSU Combi. Two different external power supplies are used. Left is an XPower open frame PSU, which was used, because it was “in stock”. The right power supply is the Mean Well RD-50A. The both boards are assembled with the different transformer types.

Figure 4: two versions of the PSU Combi

Figure 5: Finished PSU in TEKO 384 case

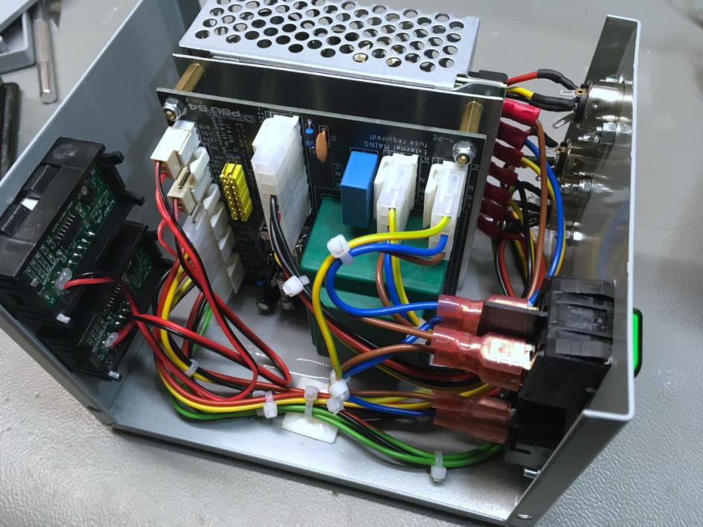
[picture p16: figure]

Drafted by Sven Petersen | Page 11 of 13 | Doc.-No.: 131-6-01-00

Figure 5 shows the finished PSU in the TEKO 384 case. The mains switch is on the front. The external PSU and the PCB fit side by side. The PSU can be mounted directly on the bottom of the case, while the PCB sits on 10mm hex bolts. The wiring of the mains and the output jacks require some space, due to the flat connectors and the bending radius of the cables.

Figure 6: Finished PSU in the Hammond 1411P case

Figure 6 shows the PSU mounted inside the Hammond 1411P case. The RD-50A is mounted upright. The PCB is attached to a fitting panel, which is screwed to the bottom of the PSU and a mounting angle. This is the most compact configuration.

Cable ties and adhesive cable posts provide a clean cable routing. The mains switch is on the back.

Two panel voltmeters are installed. This is not a requirement. The voltmeter should be calibrated with a multimeter to get a useful accuracy.

Figure 7 shows the power jacks mounted to the back panel and the connection to the RD-50A with cable lugs.

Figure 8 shows the back side of the Hammond 1411P case. The mains switch is in the back, the output cables are also in the back. The output cables are detachable, which is a nice feature in case not all outputs are used permanently. In case one or two cables should stay permanently attached, strain reliefs can be mounted on the back panel.

Figure 9 shows the mounting of the RD-50A power supply and the PCB in the Hammond case. The PCB sits on a fitting panel via 15mm hex bolts. The fitting panel is screwed to the bottom of the RD-50A. A 10mm x 10mm aluminum mounting angle is screwed to the fitting panel and mounted to the bottom of the case to provide more stability.

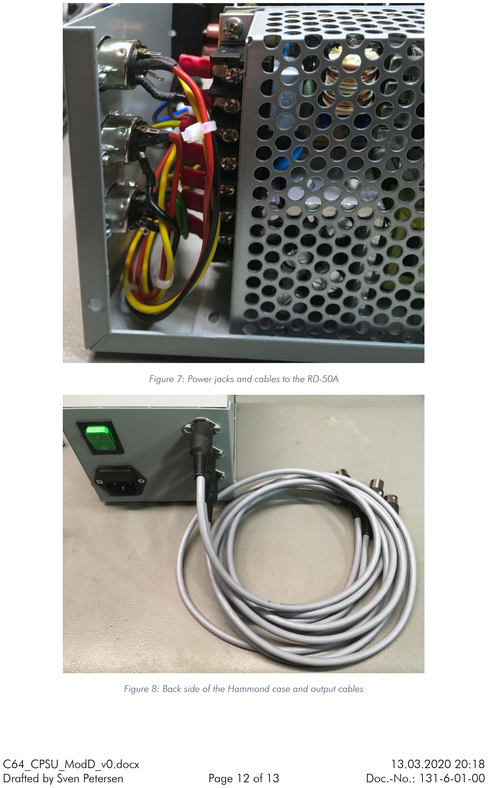
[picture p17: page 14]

Drafted by Sven Petersen | Page 12 of 13 | Doc.-No.: 131-6-01-00

Figure 7: Power jacks and cables to the RD-50A

Figure 8: Back side of the Hammond case and output cables

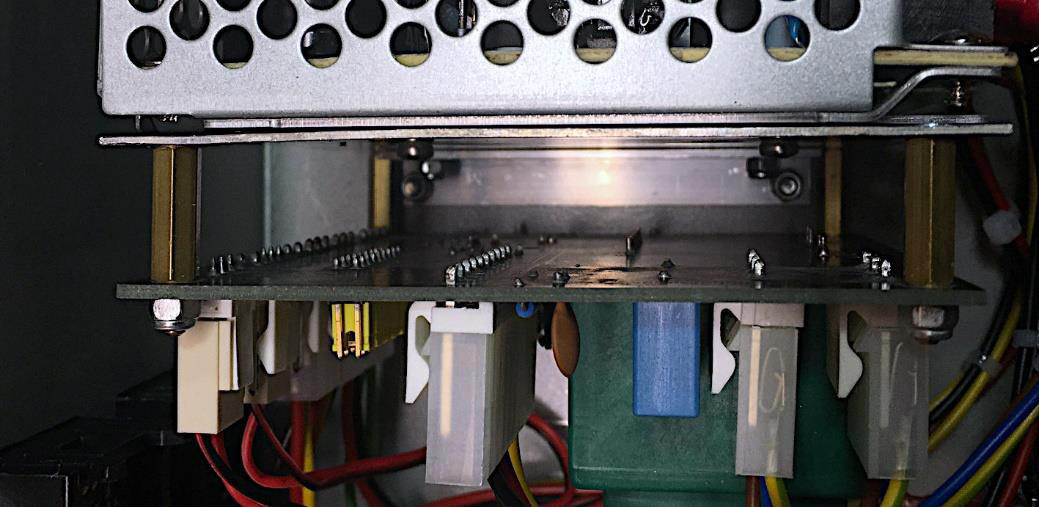
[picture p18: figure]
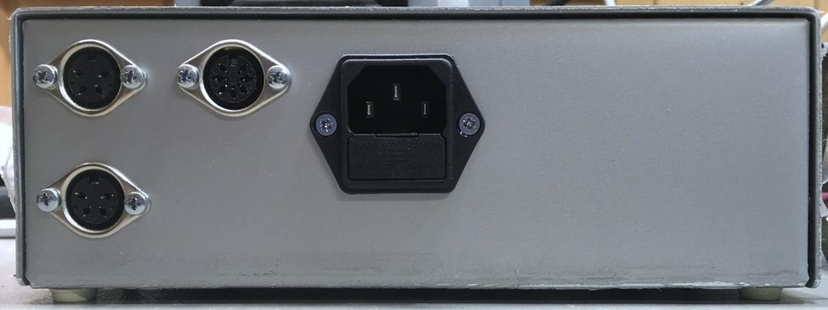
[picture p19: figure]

Drafted by Sven Petersen | Page 13 of 13 | Doc.-No.: 131-6-01-00

Figure 9: Mounting of the RD-50A and the PCB in the Hammond Case

Figure 10: Back of the Teko 384 case

Figure 10 shows the back of the Teko case 384. The (illuminated) mains switch is in the front and also serves as a power indicator.

## Further thoughts

The panel meters are not really required. In case, they are not used, the 5V on the voltage connector of the panel meter can be connected to a USB A jack, which then can power accessories like the RetroTINK video converter. This way, one more power supply can be saved. It was not tested to drive a PI1541 with it, which might require a bit more current.

Since many possible externals PSUs have a wide range input – the RD-50A is capable of 88VAC to 264VAC – the Rev. 1 of the PSU Combi will have an option for a transformer that allows 115V/230V switching.

## Testing

After finishing the power supply, it is very important to test the pinning of the output jacks/cables. A mistake could fry the connected device.

The ratings of the power supply depend on the used components. This way, the mains fuse requires to be determined. Values of 500mA to maybe 1A should be tested. The PSU combi does have an inrush current, so if the fuse is too weak, it will blow frequently. Nevertheless, the fuse should be as weak as possible.

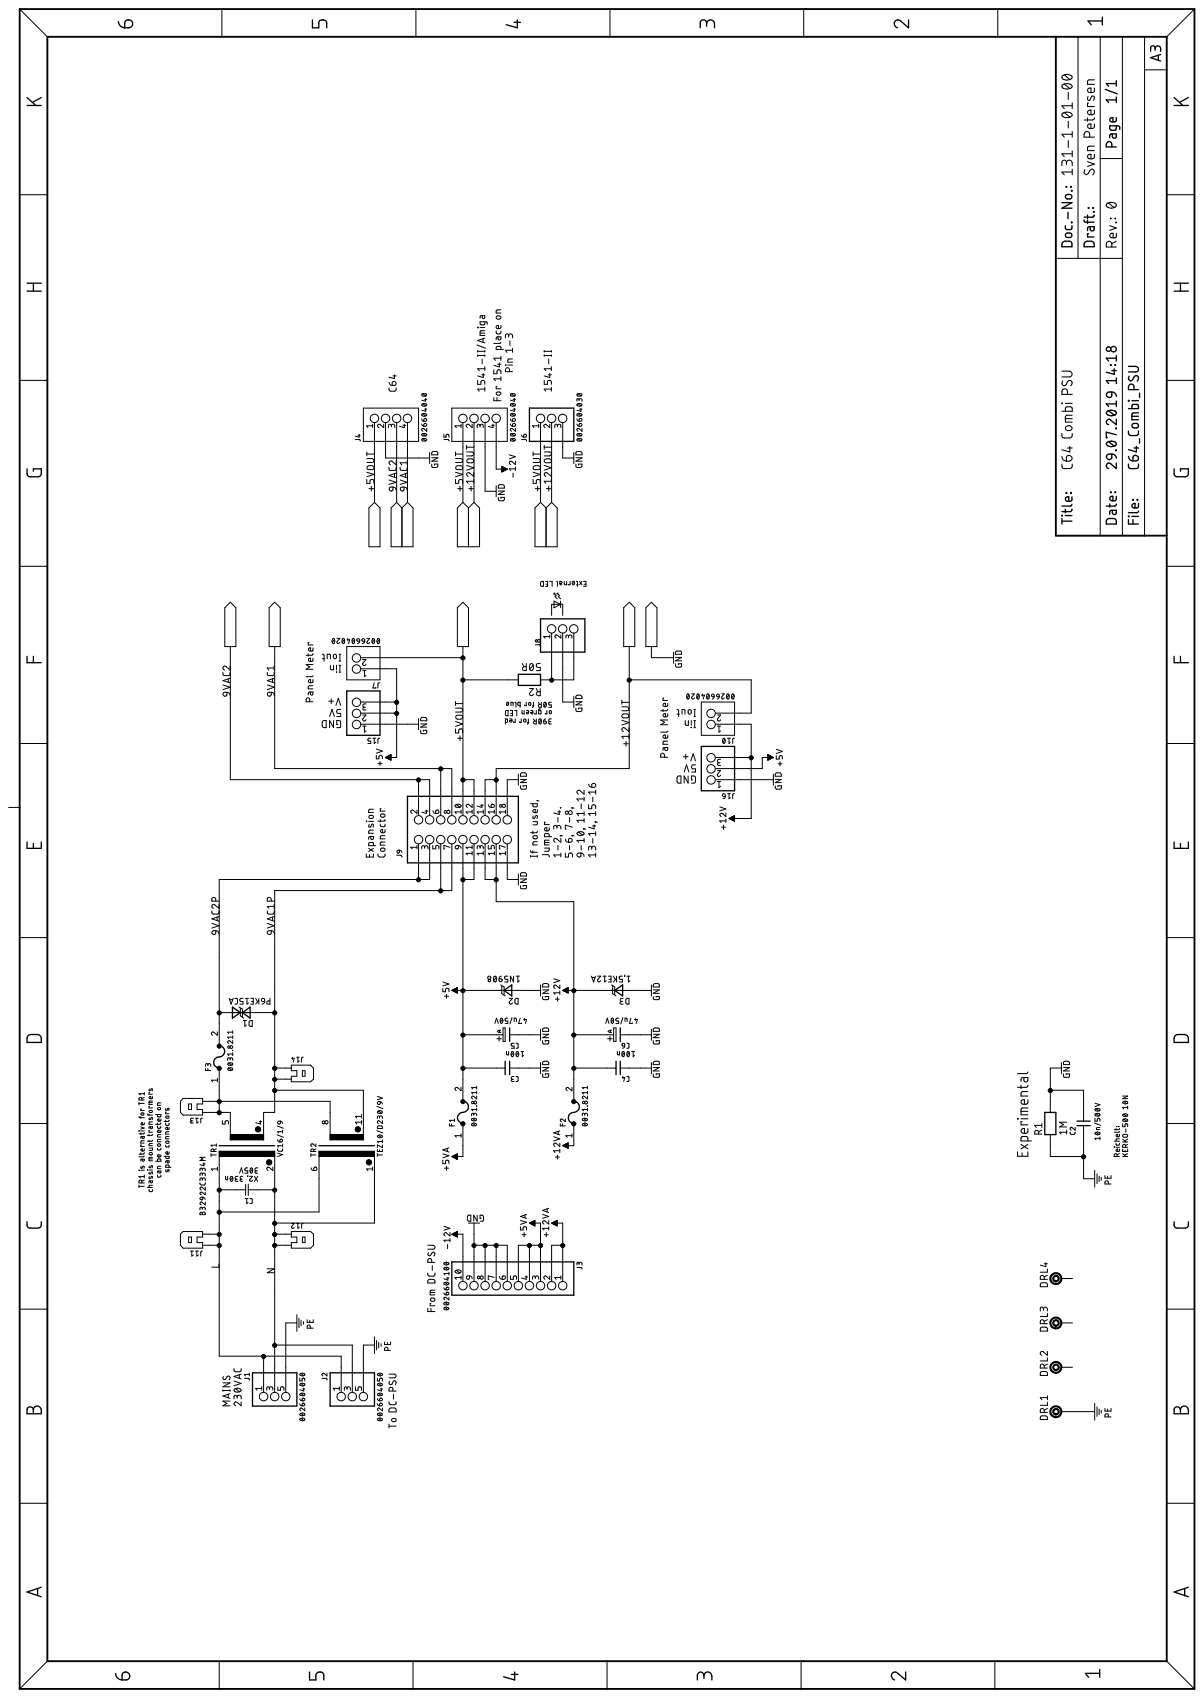
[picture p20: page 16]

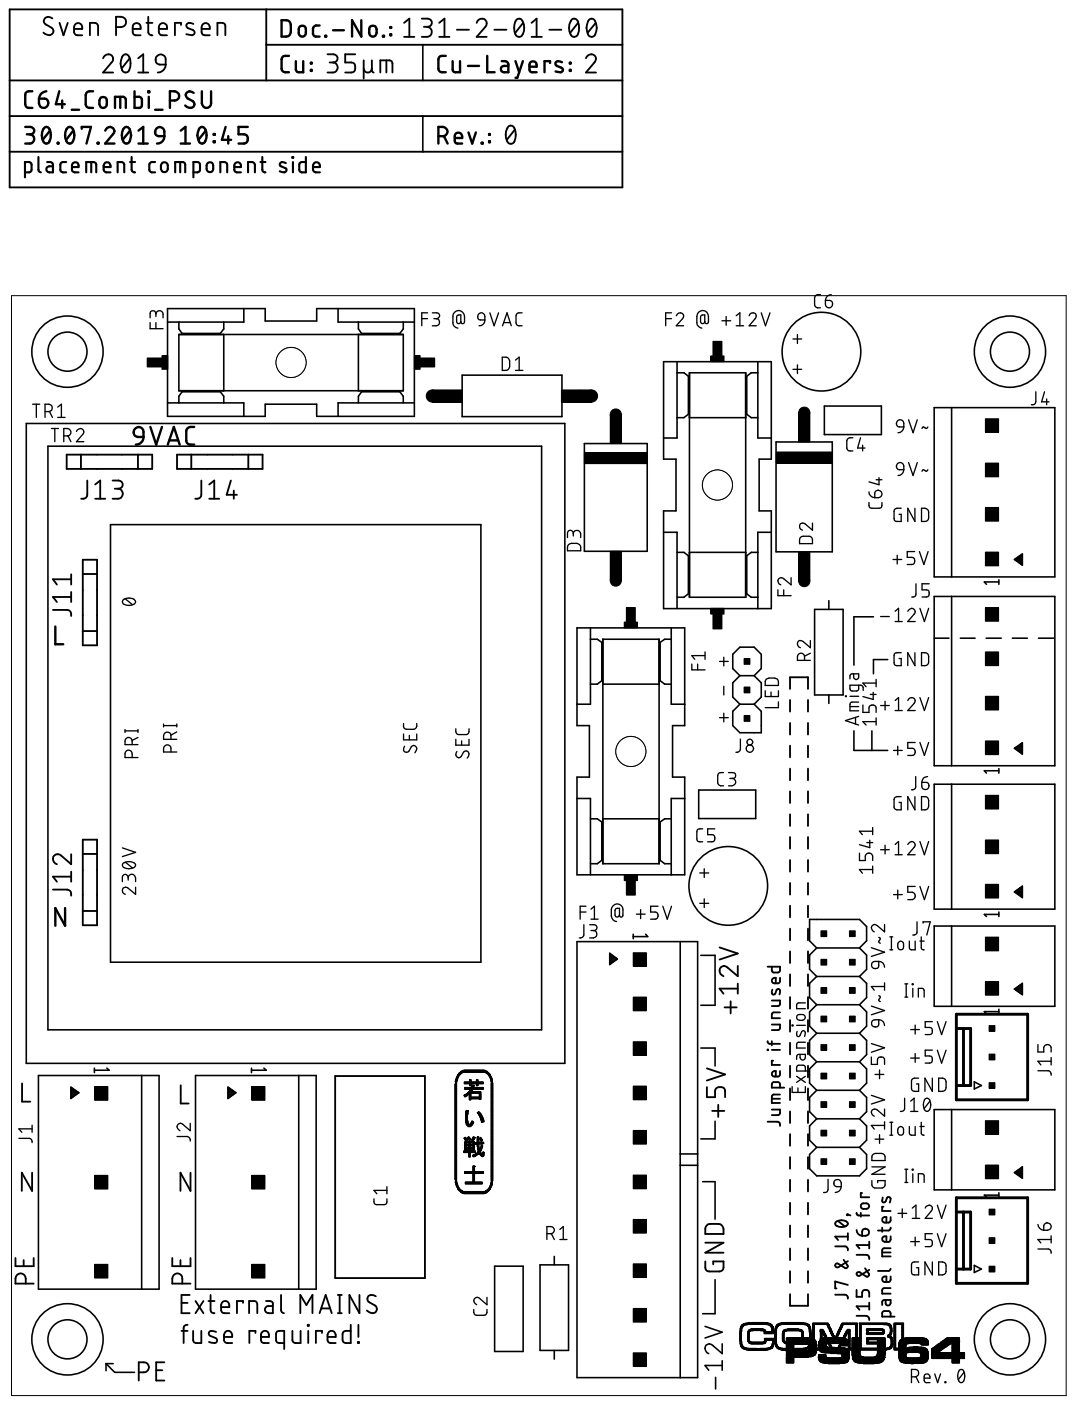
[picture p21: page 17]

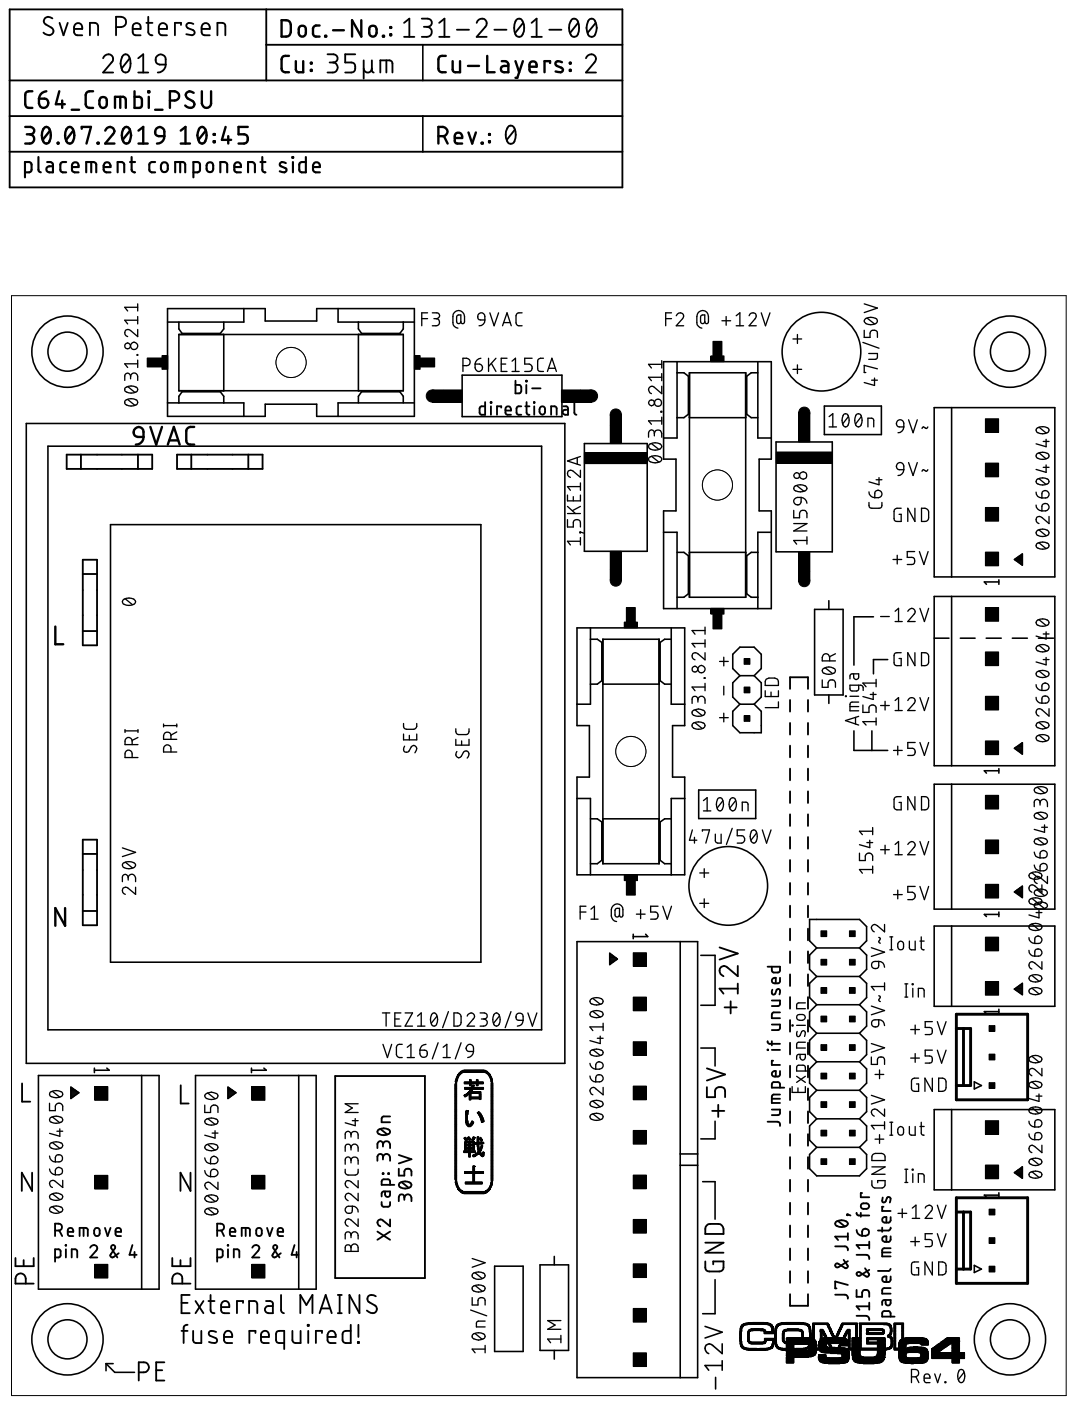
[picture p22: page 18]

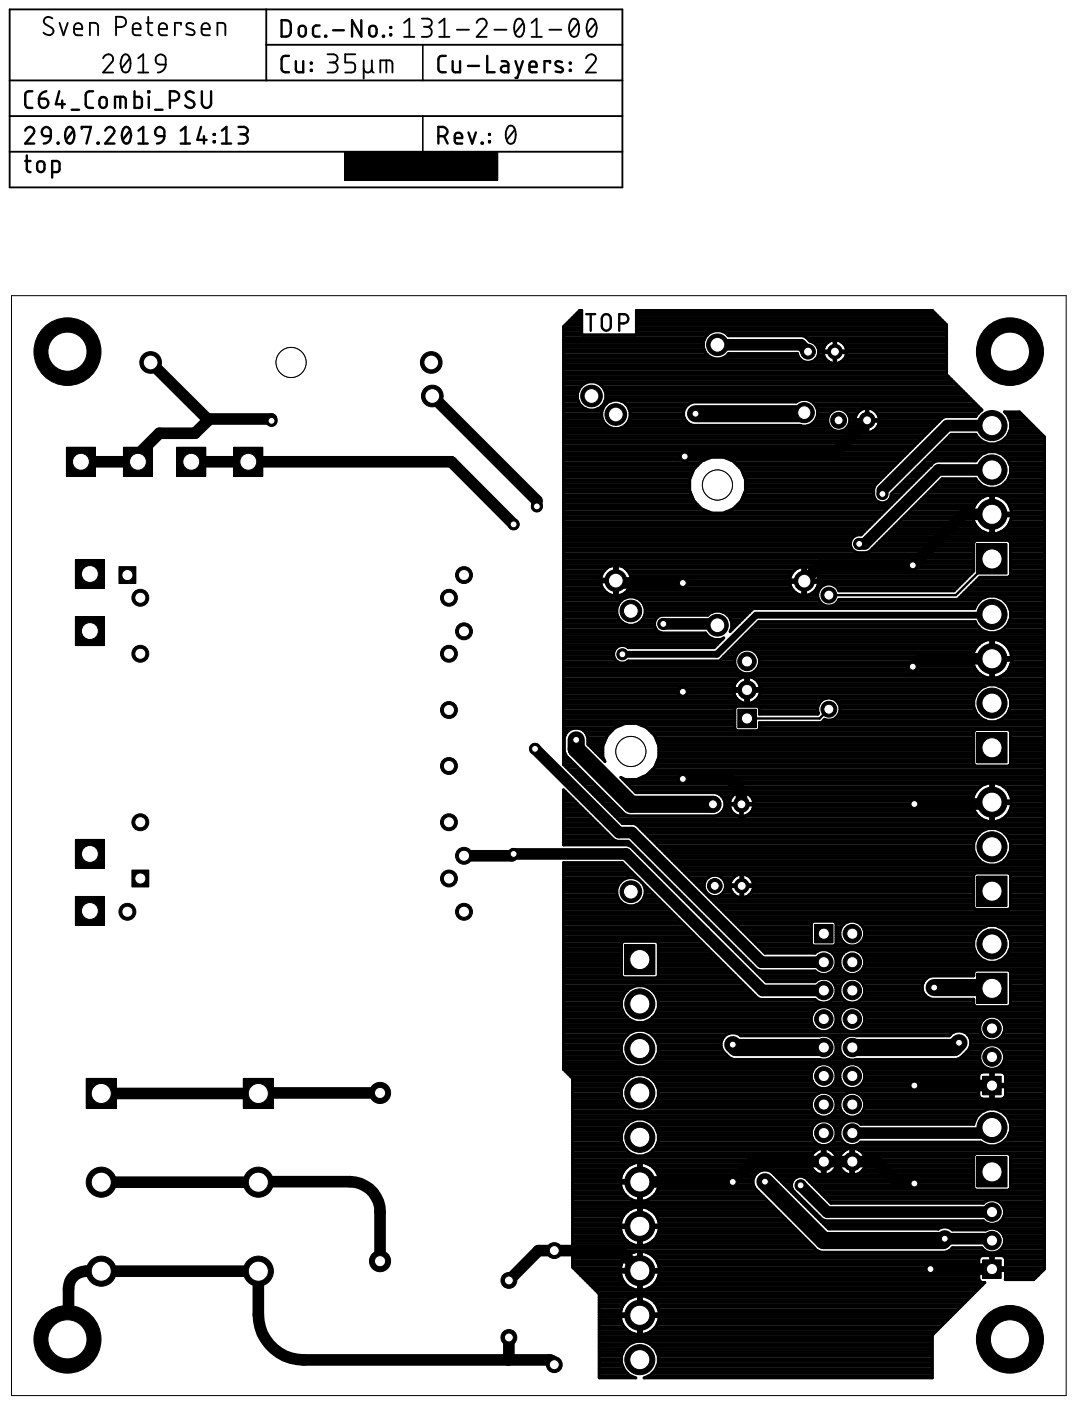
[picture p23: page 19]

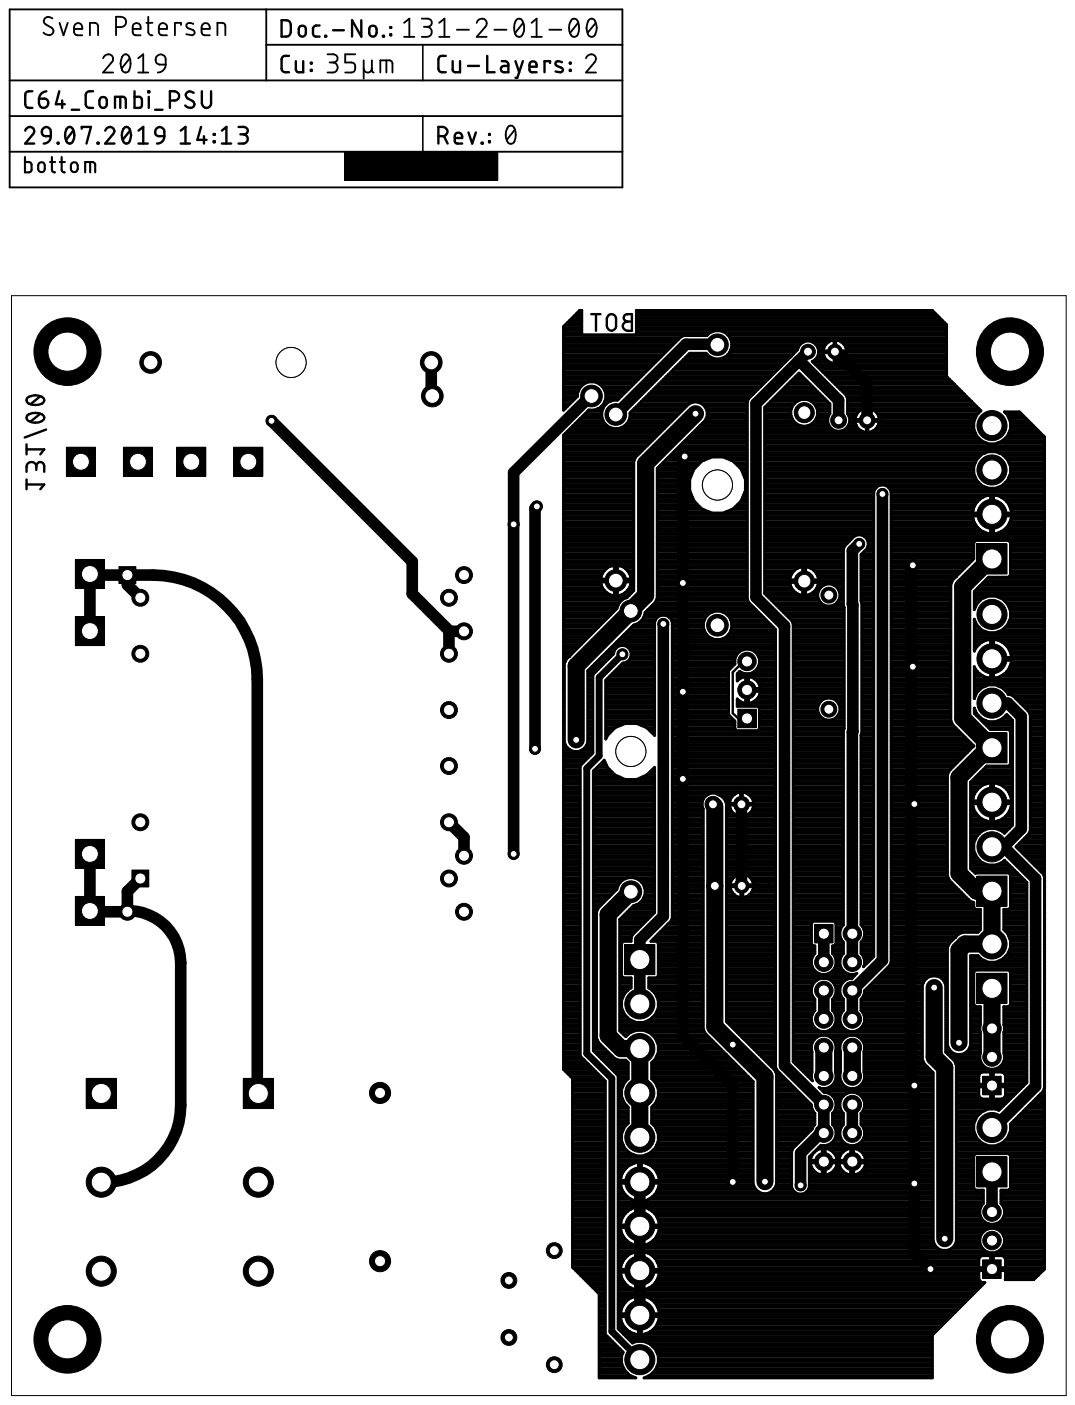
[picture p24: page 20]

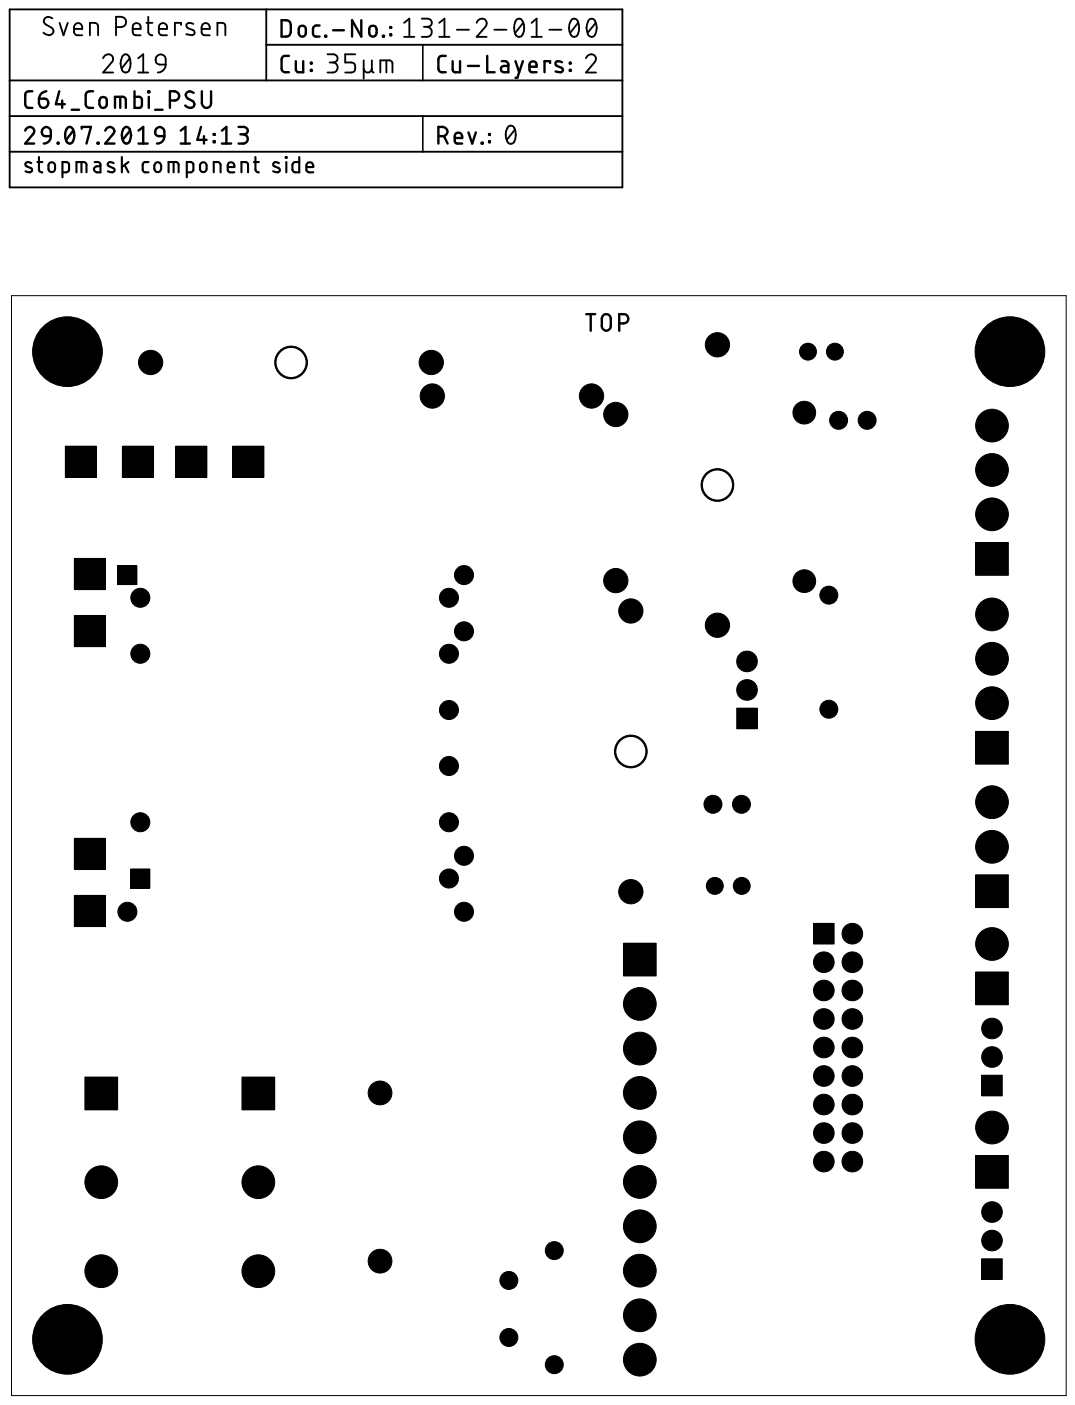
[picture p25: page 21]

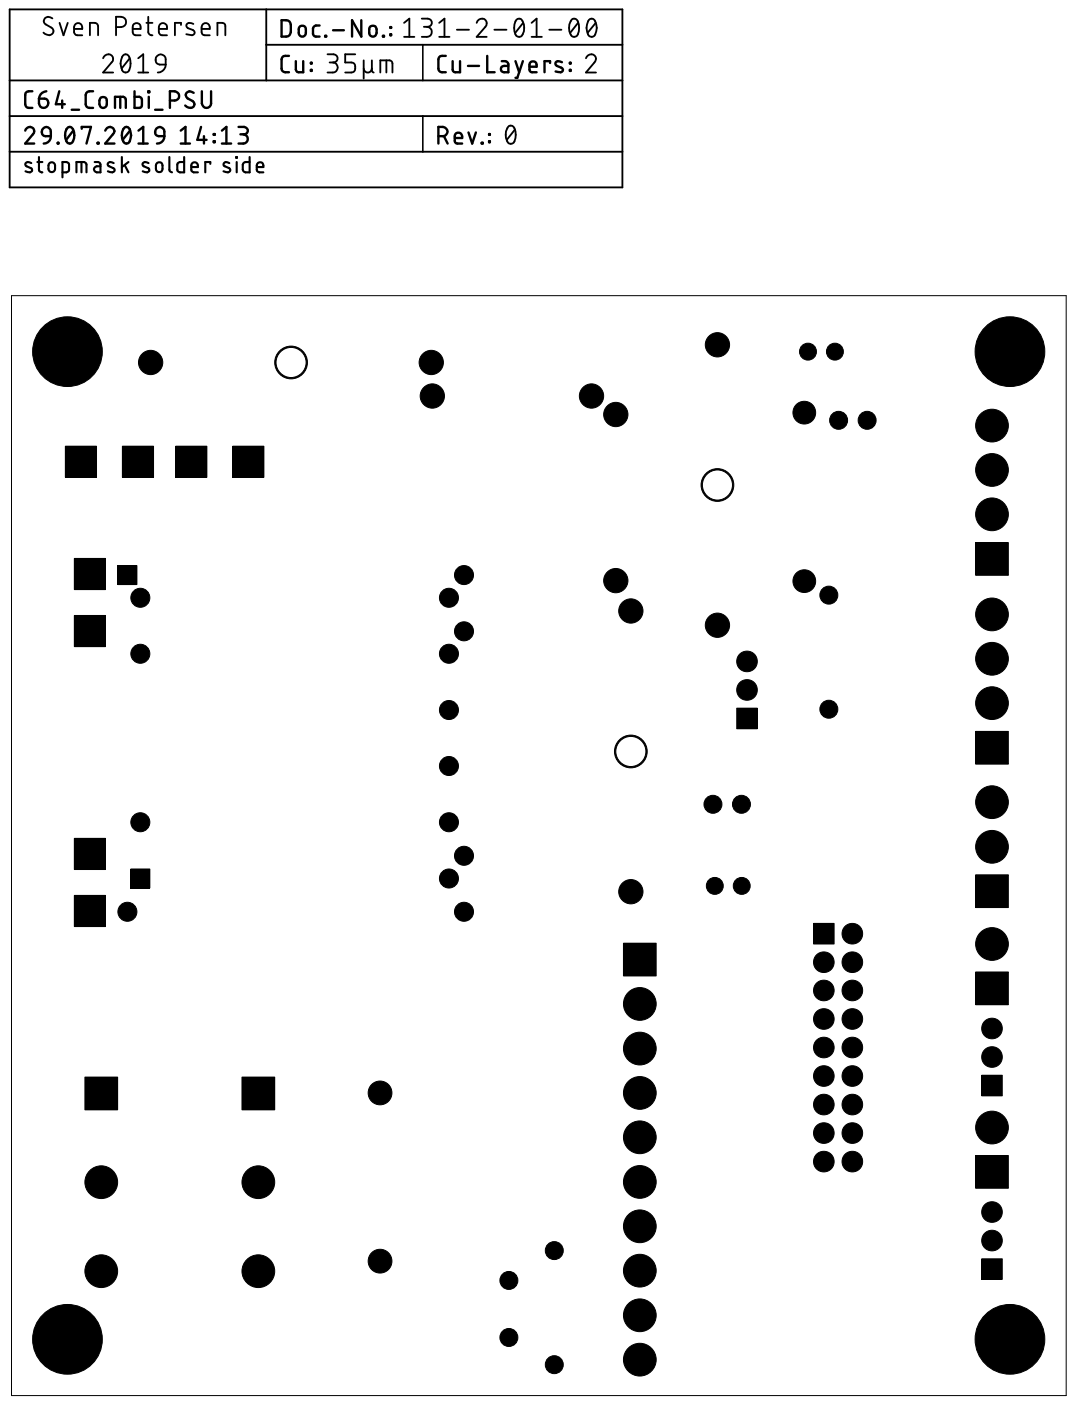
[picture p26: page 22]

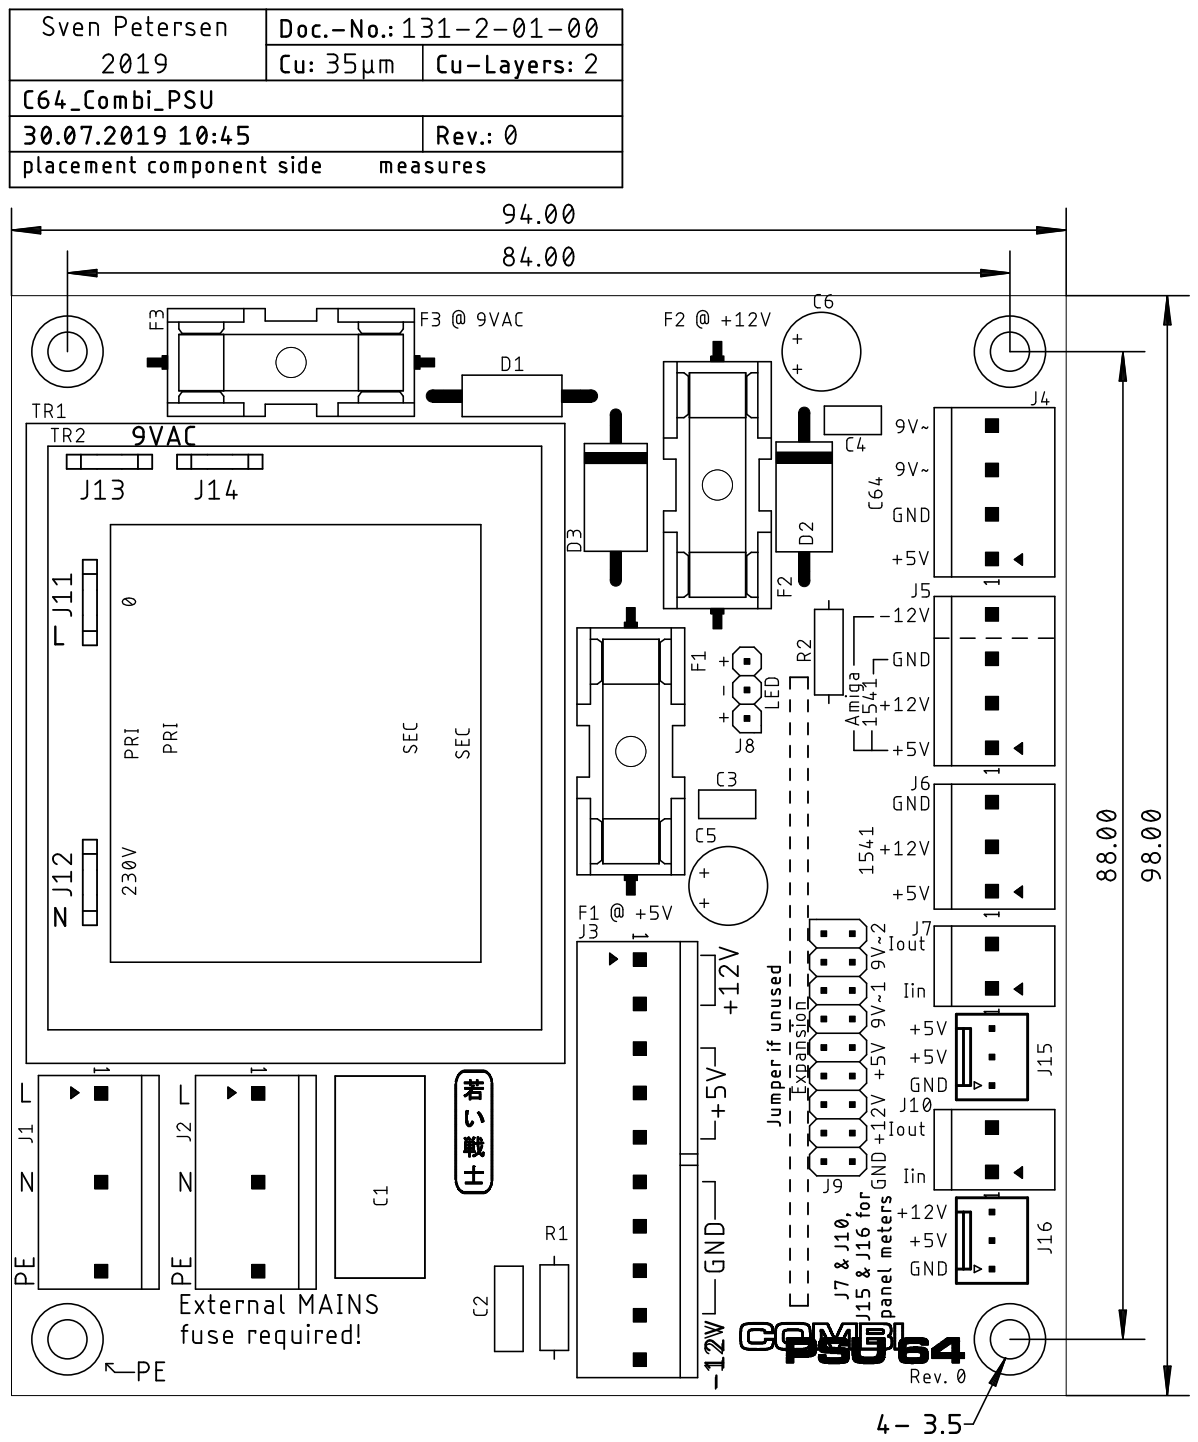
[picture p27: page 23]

Pos. Qty Value Footprint Ref.-No. Comment

1 1 131-2-01-00 2 Layer PCB Rev. 0 2 layer, Cu 35µ, HASL, 94.0 x 98.0, 1.6mm FR4

2 2 22-27-2031 6410-3P J15, J16 optional (for panel meters): Molex 6410/22-27-2031 (KK,

2.54mm, 3p), e.g. Reichelt: MOLEX 22272031, tme.eu: MX-

6410-03A

3 2 22-01-3037 (J15), (J16) crimp housing, optional (for panel meters), Molex. E.g.
Reichelt: MOLEX 22013037, tme.eu: MX-22-01-3037

4 6 08-50-0114 (J15), (J16) crimp terminal, optional (for panel meters), Molex. E.g.
Reichelt: MOLEX 8500114, tme.eu: MX-0850-0114

5 4 6.3 x 0.8 FLA6,3 J11, J12, J13, J14 optional (for chassis mount transformer), PCB mount spade

connectors

6 1 1x3p, 2.54mm 1X03 J8 standard pin header, 2.54mm pitch

7 1 dupont housing, 3p (J8) ebay, AliExpress or other
8 2 dupont terminals, female (J8) ebay, AliExpress or other

9 1 LED, blue (J8) Power LED, blue (R1 is calculated for blue)

10 1 2x9p, 2.54mm 2X09 J9 standard pin header, 2.54mm pitch

11 8 jumper, 2.54mm (J9) standard jumper (rated 3A). E.G. Reichelt: JUMPER 2,54 SW,

tme.eu: 63429-202LF

11 2 26604020 SPOX_3.96_2P J7, J10 optional (for panel meters): Molex SPOX, e.G. Reichelt: MOLEX

26604020, tme.eu: MX-26-60-4020

12 2 09503021 (J7), (J10) crimp housing, optional (for panel meters): Molex. E.g.

Reichelt: MOLEX 9503021, tme.eu: MX-2139-2A

13 4 08500106 (J7), (J10) crimp terminal, optional (for panel meters), Molex. E.g.

Reichelt: MOLEX 08500106, tme.eu: MX-2478-1-P913L (= 10

pack)

14 2 or 1 26604030 SPOX_3.96_3P J6, (J5) J5 for 1541 option, Molex SPOX, e.G. Reichelt: MOLEX

26604030, tme.eu: MX-26-60-4030

15 2 or 1 09503031 (J6), (J5) crimp housing: Molex. E.g. Reichelt: MOLEX 9503031, tme.eu:

MX-2139-3A

16 6 or 3 08500106 (J6), (J5) crimp terminal, Molex. E.g. Reichelt: MOLEX 08500106,

tme.eu: MX-2478-1-P913L (= 10 pack)

## C64 Combi PSU Rev. 0

## Bill of Material Rev. 0.0

C64_CombiPSU_BOM_v0_0.xlsx

Drafted by Sven Petersen Page 1 of 3

13.03.2020 14:50
Doc.No.: 131-5-01-00.0

Pos. Qty Value Footprint Ref.-No. Comment

## C64 Combi PSU Rev. 0

## Bill of Material Rev. 0.0

17 1 or 2 26604040 SPOX_3.96_4P J4, (J5) J5 for Amiga option, Molex SPOX, e.G. Reichelt: MOLEX

26604040, tme.eu: MX-26-60-4040

18 1 or 2 09503041 (J4), (J5) crimp housing: Molex. E.g. Reichelt: MOLEX 9503041, tme.eu:

MX-2139-4A

19 4 or 8 08500106 (J4), (J5) crimp terminal, Molex. E.g. Reichelt: MOLEX 08500106,

tme.eu: MX-2478-1-P913L (= 10 pack)

20 2 26604050 SPOX_3.96_5P3 J1, J2 Modification: Remove Pin 2 and Pin 4. Molex SPOX, e.G.
Reichelt: MOLEX 26604050, tme.eu: MX-26-60-4050

21 2 09503051 (J1), (J2) crimp housing: Molex. E.g. Reichelt: MOLEX 9503051, tme.eu:

MX-2139-5A

22 6 08500106 (J1), (J2) crimp terminal, Molex. E.g. Reichelt: MOLEX 08500106,

tme.eu: MX-2478-1-P913L (= 10 pack)

23 1 26604100 SPOX_3.96_10P J3 Molex SPOX, e.G. Reichelt: MOLEX 26604100, tme.eu: MX-

26-60-4100

24 1 09503101 (J3) crimp housing: Molex. E.g. Reichelt: MOLEX 9503101, tme.eu:

MX-2139-10A

25 10 08500106 (J3) crimp terminal, Molex. E.g. Reichelt: MOLEX 08500106,

tme.eu: MX-2478-1-P913L (= 10 pack)

26 3 0031.8211 318211 F1, F2, F3 Schurter fuse holder (5x20mm). E.g. Reichelt: PL OGN-25,

tme.eu: 0031.8211

27 1 3AT, 5x20mm (F1) fuse, refer to documentation
28 1 1.6AT, 5x20mm (F2) fuse, refer to documentation

29 1 1.6AT, 5x20mm (F3) fuse, refer to documentation

30 1 1,5KE12A DO-201 D3 12V TVS diode. E.g. ST Micro. E.g. Reichelt: 1,5KE 12A,

tme.eu: 1.5KE12A

31 2 100n C-2,5 C3, C4 Ceramic Cap, 50V, pitch 2.5mm

32 1 10n/500V C-5 C2 Ceramic Cap, 500V, pitch 5mm, Reichelt: KERKO-500 10N,

tme.eu: CCH-10K (=10 pack)

33 1 1M R-10 R1 Resistor, metal film, 5% or better, 0,6W

C64_CombiPSU_BOM_v0_0.xlsx

Drafted by Sven Petersen Page 2 of 3

13.03.2020 14:50
Doc.No.: 131-5-01-00.0

Pos. Qty Value Footprint Ref.-No. Comment

## C64 Combi PSU Rev. 0

## Bill of Material Rev. 0.0

34 1 1N5908 CB429 D2 5V TVS diode. ST Micro. E.g. Reichelt: 1N 5908, tme.eu:

1N5908

35 2 47u/50V C07/2,5 C5, C6 el. cap., diameter 7mm, pitch 2.5mm, 105°C, e.G. Reichelt:

EB-A 47U 50, tme.eu: EEUEB1H470S (= 5 pack)

36 1 50R R-10 R2 Resistor, metal film, 5% or better, 0,6W, calculated for blue led.

For red, green, yellow: 330R

37 1 B32922C3334M C-18X8-RM15 C1 X2-capacitor, 330n, 305V, EPCOS. E.g. Reichelt EPCO

B32922C3334, tme.eu: B32922C3334M

38 1 P6KE15CA CB417NP D1 15V bi-dir TVS diode, ST Micro, e.G. Reichelt: P6KE 15CA,

tme.eu: P6KE15CA

39 1 TEZ10/D230/9V TEZ10 TR2 BREVE TUFVASSONS transformer, alternative 1, tme.eu:

TEZ10/D/9V

40 1 VC16/1/9 VC16/1/9 TR1 BLOCK transformer, alternative 2, Reichelt: EI 54/18,8 109

NOTE: The BOM is not complete. The extranal components like case, mains connector, mains fuse, mains switch, external power supply,

connectors for the power supply, cables, LED holders, mounting material, cables and connectors to the C64 and 1541 and the cables depend on
your preferences and are not listed. Panel meters can be used, but are optional. For panel meters, those with three thin and two thick wires are

prefered. A 3 prong mains connector (with PE, e.g. Schurter 6200.2300, tme.eu: 6200.2300) is highly recommended and mandatory for metal
cases. A mains switch for both wires (L and N) (=DPST), like Marquard 1835.3118 (tme.eu: 1835.3118) is also recommended. For the spade

connectors on the two latter components, a red, fully isolated 6.3 x 0.8 (e.g. TE Connectivity 2-520184-2, tme.eu: 2-520184-2) are

recommended. For the wiring of mains and external power supply, cables of 0.75mm2/AWG20 of different colors are required.

C64_CombiPSU_BOM_v0_0.xlsx

Drafted by Sven Petersen Page 3 of 3

13.03.2020 14:50
Doc.No.: 131-5-01-00.0

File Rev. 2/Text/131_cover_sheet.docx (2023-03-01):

Project Documentation

C64 PSU COMBI

Project number: 131

Revision: 2

Date: 15.07.2022


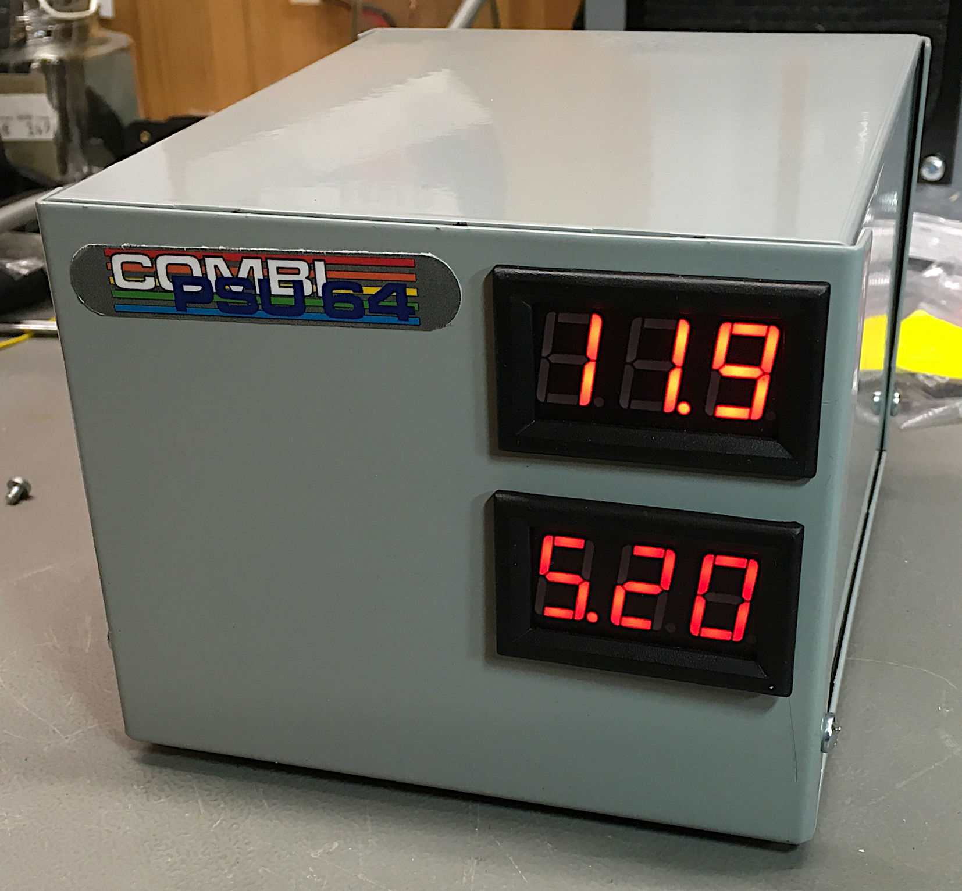
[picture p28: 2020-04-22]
Rev. 2/pictures/4267_C64_PSU_Combi.JPG

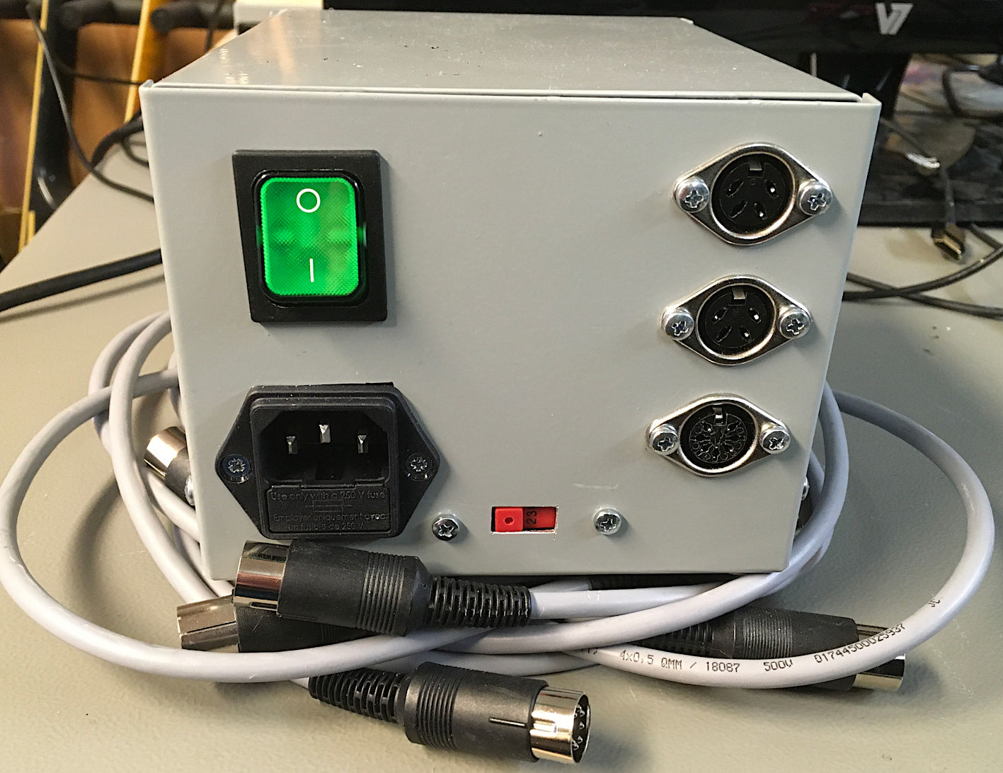
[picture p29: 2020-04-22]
Rev. 2/pictures/4402_back_panel.JPG

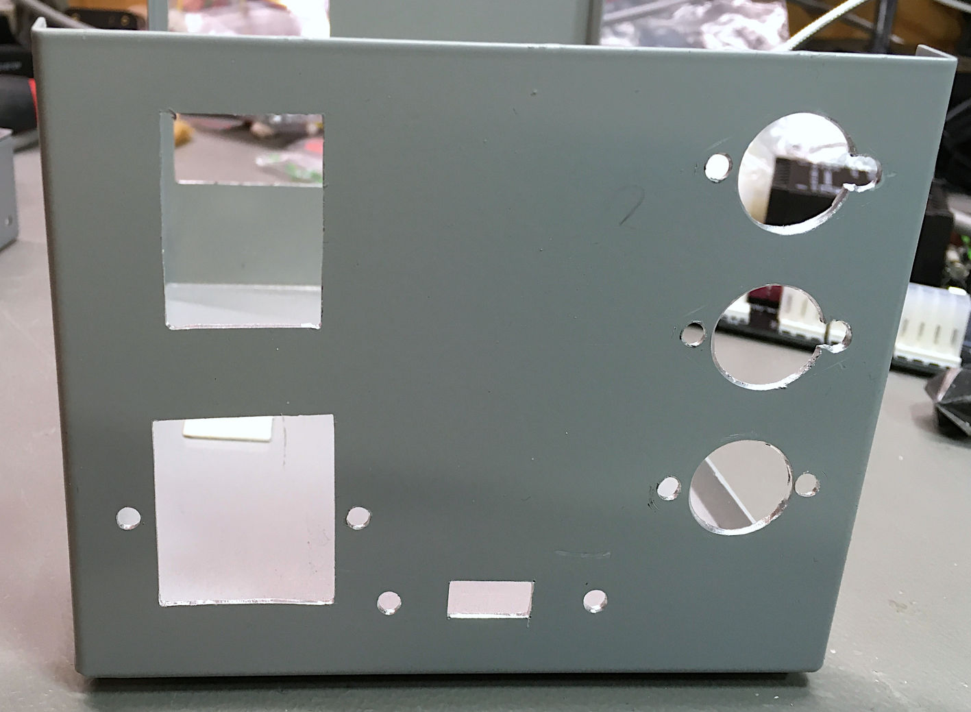
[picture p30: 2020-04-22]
Rev. 2/pictures/4254_back_panel_empty.JPG

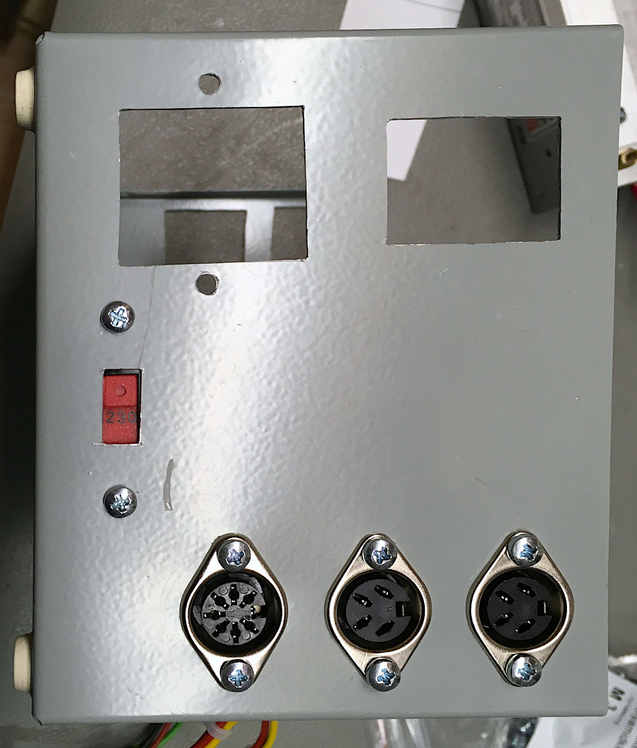
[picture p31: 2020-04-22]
Rev. 1/pictures/IMG_4255.xnbak.jpg

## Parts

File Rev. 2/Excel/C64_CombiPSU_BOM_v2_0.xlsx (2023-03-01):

C64 Combi PSU Rev. 2
Bill of Material Rev. 2.0
Pos. | Qty | Value | Footprint | Ref.-No. | Comment
1 | 1 | 131-2-01-02 | 2 Layer | PCB Rev. 2 | 2 layer, Cu 35µ, HASL, 94.0 x 98.0, 1.6mm FR4
2 | 2 | 22-27-2031 | 6410-3P | J15, J16 | optional (for panel meters): Molex 6410/22-27-2031 (KK, 2.54mm, 3p), e.g. Reichelt: MOLEX 22272031, tme.eu: MX-6410-03A
3 | 2 | 22-01-3037 |  | (J15), (J16) | crimp housing, optional (for panel meters), Molex. E.g. Reichelt: MOLEX 22013037, tme.eu: MX-22-01-3037
4 | 6 | 08-50-0114 |  | (J15), (J16) | crimp terminal, optional (for panel meters), Molex. E.g. Reichelt: MOLEX 8500114, tme.eu: MX-0850-0114
5 | 1 | 1x3p, 2.54mm | 1X03 | J8 | standard pin header, 2.54mm pitch
6 | 1 | dupont housing, 3p |  | (J8) | ebay, AliExpress or other
7 | 2 | dupont terminals, female |  | (J8) | ebay, AliExpress or other
8 | 1 | LED, blue |  | (J8) | Power LED, blue (R1 is calculated for blue)
9 | 1 | 2x9p, 2.54mm | 2X09 | J9 | standard pin header, 2.54mm pitch
10 | 8 | jumper, 2.54mm |  | (J9) | standard jumper (rated 3A). E.G. Reichelt: JUMPER 2,54 SW, tme.eu: 63429-202LF
11 | 2 or 1 | 26604030 | SPOX_3.96_3P | J6, (J5) | J5 for 1541 option, Molex SPOX, e.G. Reichelt: MOLEX 26604030, tme.eu: MX-26-60-4030
12 | 2 or 1 | 09503031 |  | (J6), (J5) | crimp housing: Molex. E.g. Reichelt: MOLEX 9503031, tme.eu: MX-2139-3A
13 | 6 or 3 | 08500106 |  | (J6), (J5) | crimp terminal, Molex. E.g. Reichelt: MOLEX 08500106, tme.eu: MX-2478-1-P913L (= 10 pack)
14 | 1 or 2 | 26604040 | SPOX_3.96_4P | J4, (J5) | J5 for Amiga option, Molex SPOX, e.G. Reichelt: MOLEX 26604040, tme.eu: MX-26-60-4040
15 | 1 or 2 | 09503041 |  | (J4), (J5) | crimp housing: Molex. E.g. Reichelt: MOLEX 9503041, tme.eu: MX-2139-4A
16 | 4 or 8 | 08500106 |  | (J4), (J5) | crimp terminal, Molex. E.g. Reichelt: MOLEX 08500106, tme.eu: MX-2478-1-P913L (= 10 pack)
17 | 2 | 26604050 | SPOX_3.96_5P3 | J1, J2 | Modification: Remove Pin 2 and Pin 4. Molex SPOX, e.G. Reichelt: MOLEX 26604050, tme.eu: MX-26-60-4050
18 | 2 | 09503051 |  | (J1), (J2) | crimp housing: Molex. E.g. Reichelt: MOLEX 9503051, tme.eu: MX-2139-5A
19 | 6 | 08500106 |  | (J1), (J2) | crimp terminal, Molex. E.g. Reichelt: MOLEX 08500106, tme.eu: MX-2478-1-P913L (= 10 pack)
20 | 1 | 26604100 | SPOX_3.96_10P | J3 | Molex SPOX, e.G. Reichelt: MOLEX 26604100, tme.eu: MX-26-60-4100
21 | 1 | 09503101 |  | (J3) | crimp housing: Molex. E.g. Reichelt: MOLEX 9503101, tme.eu: MX-2139-10A
22 | 10 | 08500106 |  | (J3) | crimp terminal, Molex. E.g. Reichelt: MOLEX 08500106, tme.eu: MX-2478-1-P913L (= 10 pack)
23 | 3 | 0031.8211 | 318211 | F1, F2, F3 | Schurter fuse holder (5x20mm). E.g. Reichelt: PL OGN-25, tme.eu: 0031.8211
24 | 1 | 3AT, 5x20mm |  | (F1) | fuse, refer to documentation
25 | 1 | 1.6AT, 5x20mm |  | (F2) | fuse, refer to documentation
26 | 1 | 1.6AT, 5x20mm |  | (F3) | fuse, refer to documentation
27 | 1 | 1,5KE12A | DO-201 | D3 | 12V TVS diode. E.g. ST Micro. E.g. Reichelt: 1,5KE 12A, tme.eu: 1.5KE12A
28 | 2 | 100n | C-2,5 | C3, C4 | Ceramic Cap, 50V, pitch 2.5mm
29 | 1 | 10n/500V | C-5 | C2 | Ceramic Cap, 500V, pitch 5mm, Reichelt: KERKO-500 10N, tme.eu: CCH-10K (=10 pack)
30 | 1 | 1M | R-10 | R1 | Resistor, metal film, 5% or better, 0,6W
31 | 1 | 1N5908 | CB429 | D2 | 5V TVS diode. ST Micro. E.g. Reichelt: 1N 5908, tme.eu: 1N5908
32 | 2 | 47u/50V | C07/2,5 | C5, C6 | el. cap., diameter 7mm, pitch 2.5mm, 105°C, e.G. Reichelt: EB-A 47U 50, tme.eu: EEUEB1H470S (= 5 pack)
33 | 1 | 50R | R-10 | R2 | Resistor, metal film, 5% or better, 0,6W, calculated for blue led. For red, green, yellow: 330R
34 | 1 | B32922C3334M | C-18X8-RM15 | C1 | X2-capacitor, 330n, 305V, EPCOS. E.g. Reichelt EPCO B32922C3334, tme.eu: B32922C3334M
35 | 1 | P6KE15CA | CB417NP | D1 | 15V bi-dir TVS diode, ST Micro, e.G. Reichelt: P6KE 15CA, tme.eu: P6KE15CA
36 | 1 | TEZ10/D230/9V | TEZ10 | TR2 | BREVE TUFVASSONS transformer, option 230V only, tme.eu: TEZ10/D/9V
37 | 1 | BV UI 304 0153 | UI30 | TR1 | Hahn transformer, option 115V/230V, tme.eu: BVUI3040153
38 | 1 | 10321041 | SPOX_5.08_4P | J2 | MOLEX, option: 115V/230V switch, tme.eu: MX-5281-04A
39 | 1 | 10013046 |  | (J2) | MOLEX, option: 115V/230V switch., tme.eu: MX-5197-04, Farnell: 2612656 , Mouser: 538-10-01-3046 , Digikey: WM9124-ND
40 | 4 | 08701031 |  | (J2) | Molex Crimp terminal, option 115V/230V, Farnell: 2060658, rs-online.com: 670-6265, Mouser 538-08-70-1031-CT, Digikey: WM18820CT-ND
41 | 1 | T22205B436B |  | (J2) | Bulgin, option 115/230V (switch), tme.eu: AE-T22205B
42 | 123cm | AWG21/0.5mm², red |  |  | Cable
43 | 90cm | AWG21/0.5mm², yellow |  |  | Cable
44 | 128cm | AWG21/0.5mm², black |  |  | Cable
45 | 64cm | AWG21/0.5mm², green |  |  | Cable
46 | 56cm | AWG21/0.5mm², blue |  |  | Cable
47 | 56cm | AWG21/0.5mm², brown |  |  | Cable
48 | 34cm | AWG21/0.5mm², green/yellow |  |  | Cable
49 | 10cm | AWG24/0.25mm², red |  |  | Cable
50 | 10cm | AWG24/0.25mm², black |  |  | Cable
49 | 3cm | 2.4/1.2mm |  |  | shrinkable sleve, shrink ration 1:2
50 | 24cm | 3.2/1.6mm |  |  | shrinkable sleve, shrink ration 1:2
50 | 7 | FastOn 6.3x0.8, full iso, red |  |  | crimp connector, e.g. tme.eu 2-520183-2
51 | 7 | Fork connectors, M3, iso, red |  |  | crimp connector, e.g. tme.eu ST-090/R
52 | 1 | DIN jack, 7-way, panel mount |  |  | e.b. tme.eu: DC-109
53 | 2 | DIN jack, 4-way, panel mount |  |  | e.g. tme.eu: MAB4
54 | 1 | Hammond 1411P |  |  | Aluminum case, tme.eu: HM-1411P
55 | 1 | Mounting plate |  |  | Aluminum sheet (99mm x 97mm x 2mm), see drawing: Doc. No. 131-3-01-01
56 | 75mm | 10mm/20mm x 1.5mm |  |  | Aluminum angle profile, see drawing: Doc. No. 131-3-01-01
57 | 8 | M3x10, countersunk |  |  | Screw, DIN 965
58 | 18 | M3, selflocking nut |  |  | DIN 985
59 | 9 | M3, toothed washer |  |  | DIN 6798
60 | 4 | M3/15mm, male/female |  |  | spacer
61 | 10 | M3x10 |  |  | DIN 7985
62 | 10 | M3 washer (3.2mm) |  |  | DIN 125A
63 | 2 | M3x6 |  |  | DIN 7985
64 | 22 | W2.5/L100 |  |  | Cable tie, width 2.5mm, length 100mm, e.g. tme.eu: BMB1025
65 | 1 | RD-50A |  |  | Mean Well DC PSU, e.g. tme.eu: RD-50A
66 | 2 | DIN plugs, 7-way |  |  | e.g. tme.eu MAS70SGR
67 | 4 | DIN plugs, 4 way |  |  | e.g. tme.eu: MAS40
68 | 3.9m | 4xAWG21/0.5mm² |  |  | Cable
69 | 1 | adhesive socket |  |  | for cable ties/cabeling
70 | 1 | 6200.2300 |  |  | Marquardt, appliance connector, tme.eu: 6200.6300
71 | 1 | 1835.3118 |  |  | Marquardt, illuminated mains switch, tme.eu: 1835.3118
72 | 1 | 0026604020 | SPOX_3.96_2P | J10 | Molex KK 396 Header, Vertical, Friction Lock, 2 Circuits
73 | 1 | 09503021 |  | (J10) | KK 3.96mm Crimp Terminal Housing, Friction Ramp, 2 Circuits
74 | 2 | 08500106 |  |  | crimp terminal, Molex. E.g. Reichelt: MOLEX 08500106, tme.eu: MX-2478-1-P913L (= 10 pack)

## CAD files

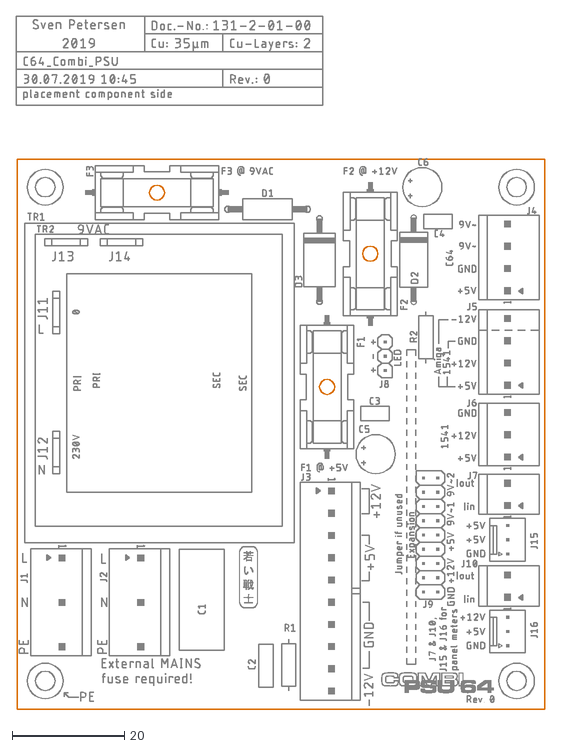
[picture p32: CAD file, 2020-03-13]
Rev. 0/AutoSketch/C64_Combi_PSU.dxf
94.2 x 123.5

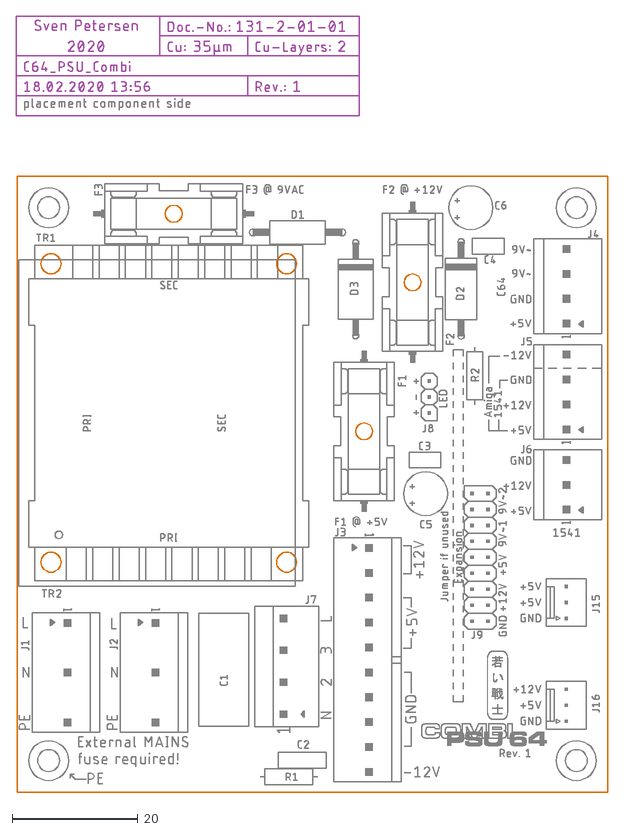
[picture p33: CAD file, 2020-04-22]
Rev. 2/AutoSketch/C64_PSU_Combi.dxf
94.2 x 123.5

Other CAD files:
Rev. 2/AutoSketch/back panel.DWG
Rev. 2/AutoSketch/bottom.DWG
Rev. 2/AutoSketch/MountPlate.DWG

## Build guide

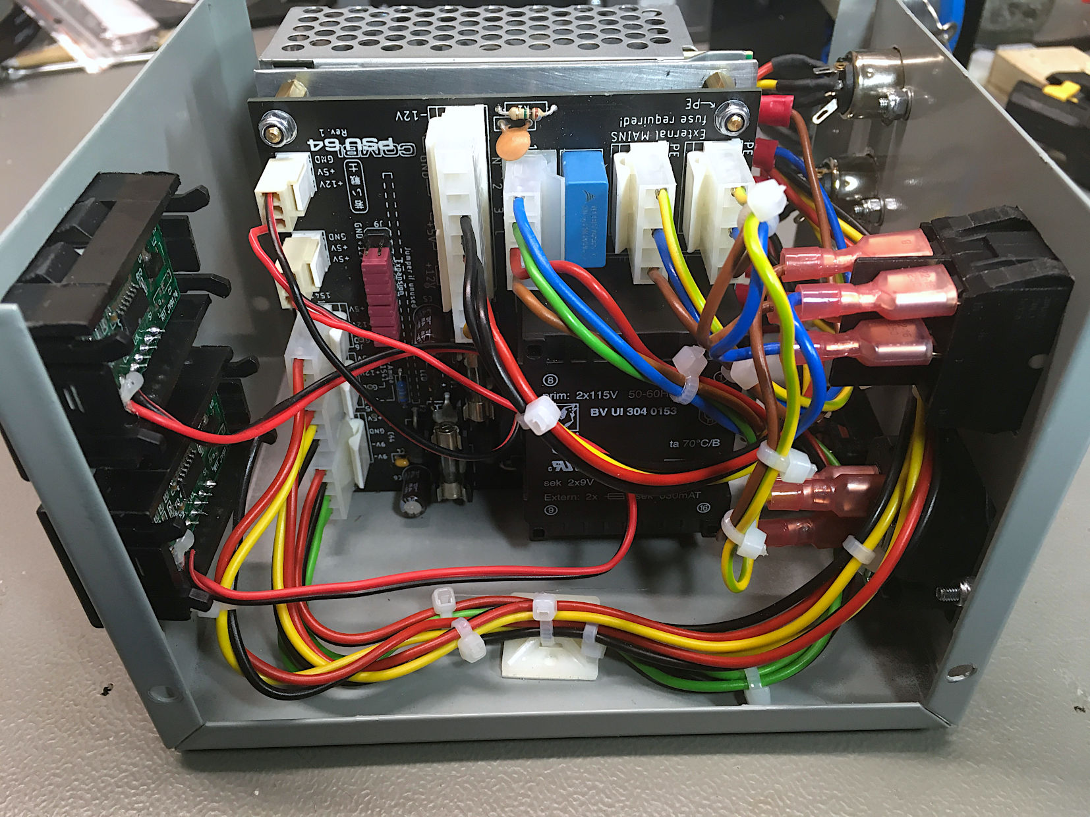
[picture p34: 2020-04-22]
Rev. 2/pictures/4300_cables_installed.JPG

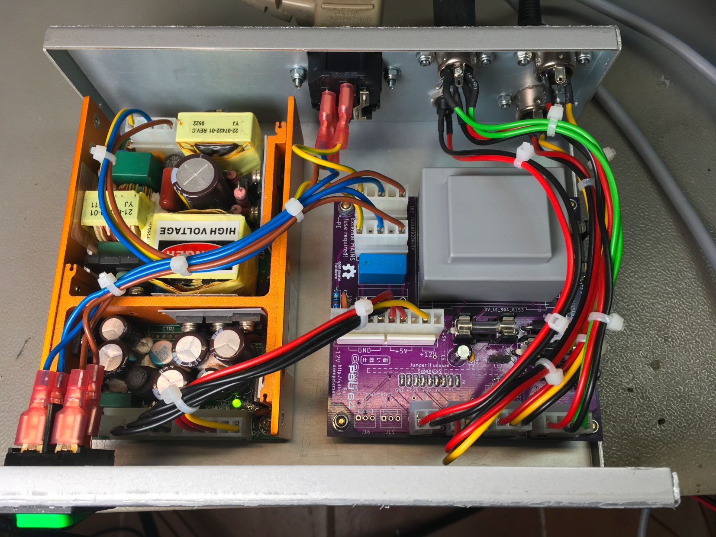
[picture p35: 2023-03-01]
Rev. 2/pictures/2488_-_PCB_Rev2_installed.JPG

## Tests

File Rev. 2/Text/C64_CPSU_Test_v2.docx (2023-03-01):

C64 PSU Combi Rev. 2

Testing

# Device Under Test/Used Equipment

The test was carried out with a PCB assembly Rev. 1. The DC-power supply was a Mean Well RD-50A. The 5V output of said DC-power supply was set to 5.2V. The DIN power cables were made from 4x0.5mm²(AWG21) cables and are 130cm long.

The voltage measurements were done with a Fluke 89IV, the current measurements with a Voltcraft VC160 multimeter.

The PSU was loaded with load resistors

Load Resistor nominal | Measure resistance (@22°C)
4.7Ω/10W | 4.9Ω
10Ω/25W | 10.1Ω
18Ω/25W | 18.1Ω

The value of the load resistors varies with temperature.

# Output Voltages

## Measurements (Vmains = 230VAC/50Hz)

Voltage nominal | Load Resistor | Voltage (no load) | Voltage (load) | Current (loaded)
+5V | 4.7Ω | 5.16V | 4.98V | 1.01A
+12V | 10Ω | 12.0V | 11.55V | 1.14A
9VAC | 10Ω | 12.6VAC | 10.05VAC | 0.99A(AC)

The 9VAC output is not regulated, like in the original power supply, it is the output voltage of a transformer. The rated output voltage only applies when the nominal load is connected. This value is not critical for the operation, since the internal voltages of the C64, which are generated from the 9VAC are regulated. The higher than rated voltage without load and the high voltage drop with a 1A load are a normal behavior of transformers.

The voltage drop of the +12V is not critical for the operation, too. The sources of the voltage drop will be tracked, though.

The little voltage drop of the +5V (with load) is not critical, since the voltage of the DC power supply can be set higher if required. 5.2V seems to be an ideal setting. However, the cause of the voltage drop needs to be investigated.

## Measurements (Vmains = 115VAC/50Hz)

Voltage nominal | Load Resistor | Voltage (no load) | Voltage (load)
+5V | 4.7Ω | 5.21V | 4.98V
+12V | 10Ω | 12.01V | 11.50V
9VAC | 10Ω | 12.4VAC | 9.80VAC

The measurements with 115V Mains were performed with a 230V to 115V transformer (Bronson++/TI-300). The mains selector switch was set to 115V.

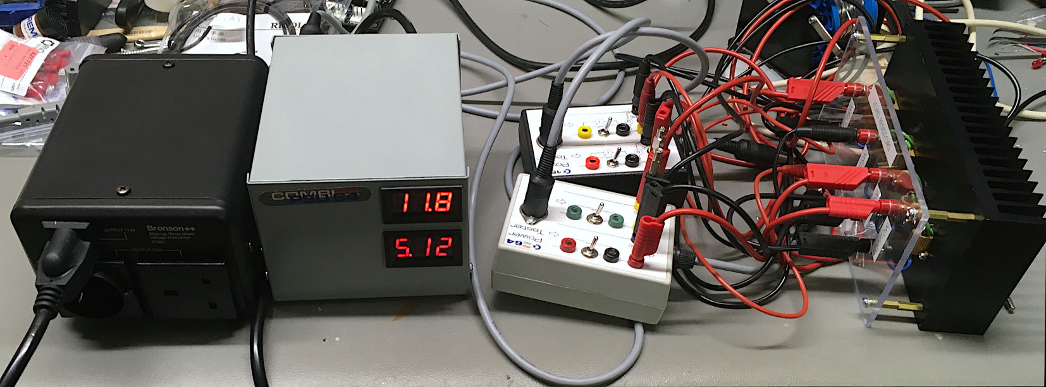
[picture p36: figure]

Figure 1: test setup with 115V mains transformer

## Tracking the +5VDC

The voltage with load, measured at J3 is 5.200V. The voltage measured at the output connector for the C64 (J4) is 5.146V. The voltage measured at the (C64) output jack (loaded) of the PSU was 5.130V. The voltage drop between the DC-PSU and the output jack totals 70mV, which is an acceptable value. At the DIN connector of the cable (at the PSU side, a value of 5.125 V was measured. 5.016V were measured at the DIN connector at the load side. 4.984V were measured inside at the power test box.

Item | Voltage drop
PCB | 54mV
Cable to C64 DIN connector | 16mV
DIN jack – DIN plug (PSU) | 5mV
Cable | 109mV
DIN plug – DIN jack (Test box) | 32mV

Most of the voltage drop occurred via the cable. The resistance of a 0.5mm² coper cables is approximately 43.4mΩ/meter. This totals in about 113mΩ for the 2x1.3m (+5V lead and ground lead), which proves the measurement (0.113Ω x 1.01A = 114mV).

## Tracking the +12V

Measurement | Reading | Drop
@J3 (no load) | 11.999V
@ DC-PSU (with load 10Ω) | 11.789V | Regulation: 210mV
@J3 (with load 10Ω) | 11.789V
@J6 (with load) | 11.719V | 70mV
@output jack (with load) | 11.702V | 17mV
@ DIN plug/output cable (PSU side) | 11.697V | 5mV
@ DIN plug/output cable (Tester side) | 11.538V | 159mV

The load regulation is contributing most of the voltage drop when a load is applied. This is a property of the DC PSU. But again, the cable is clearly contributing a lot to the voltage drop, more than the rest of the system. The load is higher than a regular disk drive, though.

# Thermal testing

Two K-type thermo couples have been installed in the device under test. T1 was positioned above the DC power supply, T2 above the transformer (Figure 2). The case was closed, the cut out for one panel meter that was removed to feed the thermo couple through the front of the case.

The +5V was loaded with 4.7Ω in parallel with a 10Ω load resistance, which results in a 3.2Ω load. The +12V was loaded with 10Ω and the 9VAC with 18Ω.

The test was conducted over 5 hours. The temperatures were monitored (Figure 3).

Time | Sensor T1 | Sensor T2
0:00h | 21.5°C | 21.5°C
1:05h | 37.3°C | 39.3°C
1:41h | 39.2°C | 42.9°C
2:41h | 40.1°C | 45.0°C
3:10h | 39.7°C | 45.0°C
5:18h | 39.9°C | 44.3°C

The temperatures stabilized over time. According to the datasheet the maximum ambient temperature for the Mean Well RD-50 is 70°C and for the transformer, it is 70°C as well. Those limits are by far not reached. Thus, the thermal properties of this power supply are not critical.

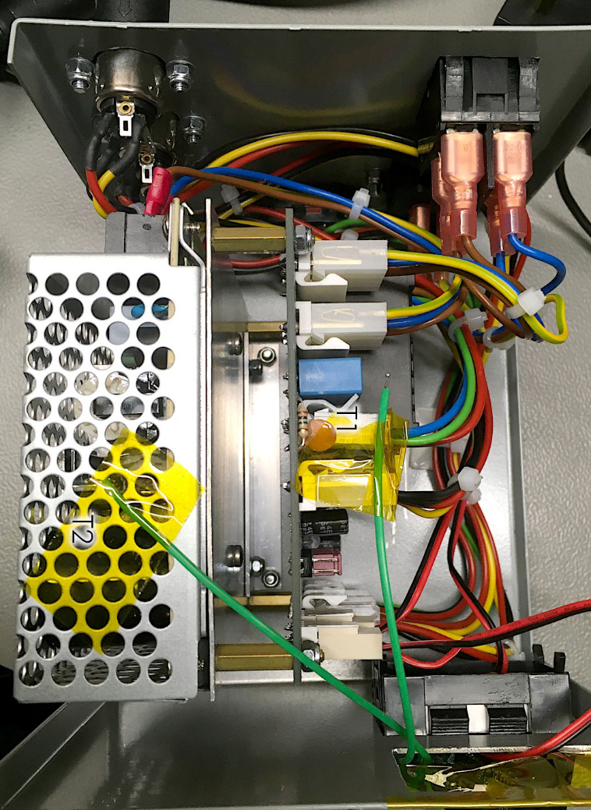
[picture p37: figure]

Figure 2: Position of the thermo couples

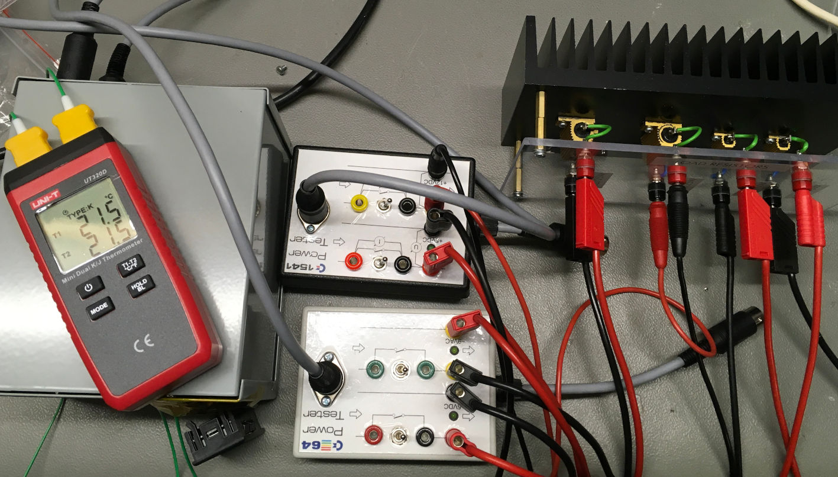
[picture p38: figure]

Figure 3: Thermal test setup

The thermal image Figure 4) shows, that the transformer is the warmest component in the design.

The temperatures in Figure 4 are not accurate, since the emissivity was set to “matt surfaces”. The maximum temperature in at the left is high due to the glossy kapton tape. So, the picture has to be interpreted as “qualitative”.

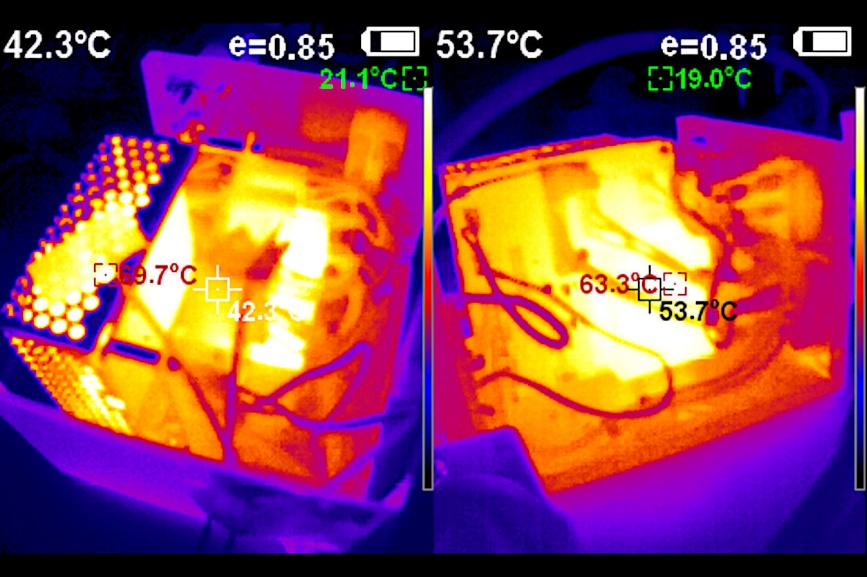
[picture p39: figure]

Figure 4: Thermal image of the PSU combi at the end of the test

# Noise measurement

The noise measurements were carried out with a load:

- +5VDC: 3.2Ω
- +12VDC: 10Ω
- 9VAC: 18Ω

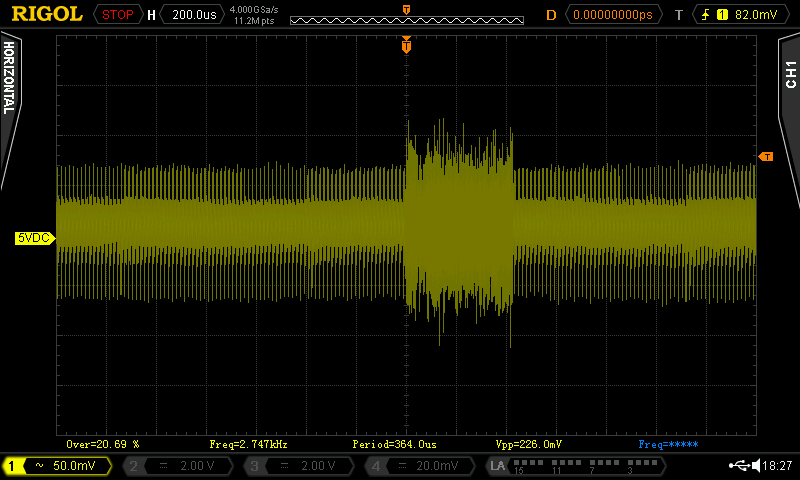
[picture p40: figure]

Figure 5: 5VDC (1div=200µs): Vpp =226mV

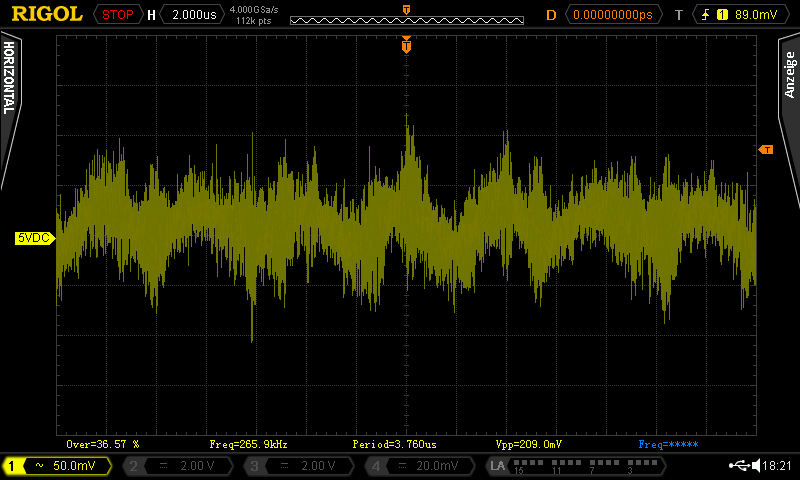
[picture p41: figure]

Figure 6: 5VDC (1div = 2µs): Vpp = 209mV

The noise on +5VDC is a property of the DC PSU (Mean Well RD-50A). Figure 5 shows, that this noise is a periodic phenomenon. Figure 6 shows this noise burst in detail.

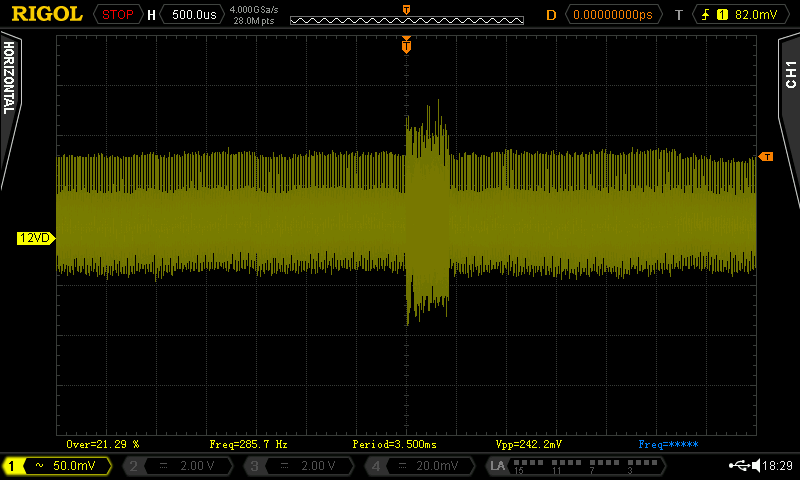
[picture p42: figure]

Figure 7: +12VDC (1div = 500µs): Vpp = 242mV

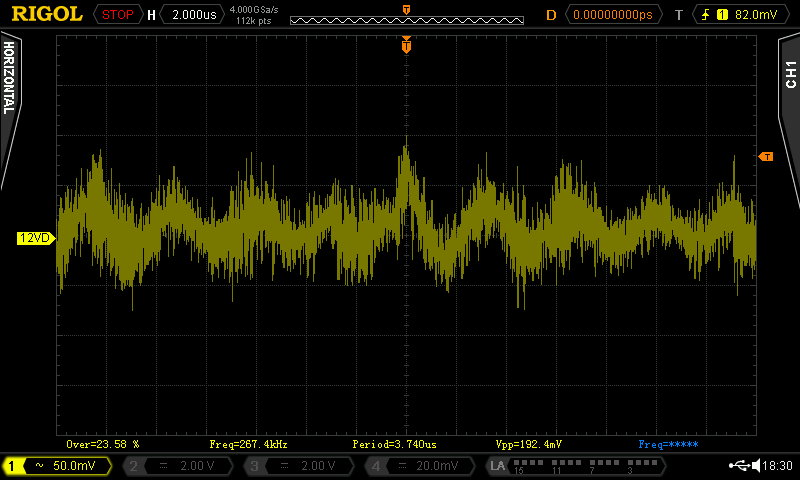
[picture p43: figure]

Figure 8: +12VDC (1div = 2µs): Vpp = 192mV

The noise on +12VDC is a property of the DC PSU. Figure 7 shows, that this noise is a periodic phenomenon. Figure 8Figure 6 shows this noise burst in detail.

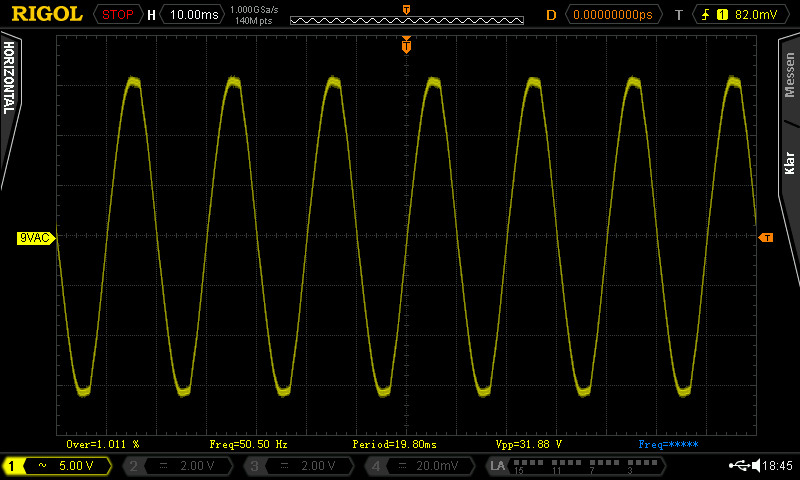
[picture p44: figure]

Figure 9: 9VAC

Figure 9 shows the 9VAC. 31.88Vpp means an amplitude of 15.94V. This is not the RMS value, which is measured with the multimeter. The sinewave looks properly, it is not heavily distorted.

# Real Life Test

The power supply was tested with the C64 ASSY

- 250407
- 250425
- 250466
- 250469

And two 1541-II. All setups worked without a problem.

# Rev. 2

Rev. 2 is technically not different from Rev. 1. The board was installed instead of Rev. 1, a barrel connector was added and it is serving as the daily driver in my setup.


Figure 10: PCB Rev.2 installed

# Conclusion

The C64 PSU combi Rev. 2 is fully functional.

C64_CPSU_Test_v2.docx 01.03.2023 22:45 Drafted by Sven Petersen Page 2 of 2 Doc.-No.: 131-6-02-02

C64_CPSU_Test_v2.docx 01.03.2023 22:45 Drafted by Sven Petersen Page 1 of 1 Doc.-No.: 131-6-02-01

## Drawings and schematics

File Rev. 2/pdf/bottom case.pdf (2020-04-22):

127,2

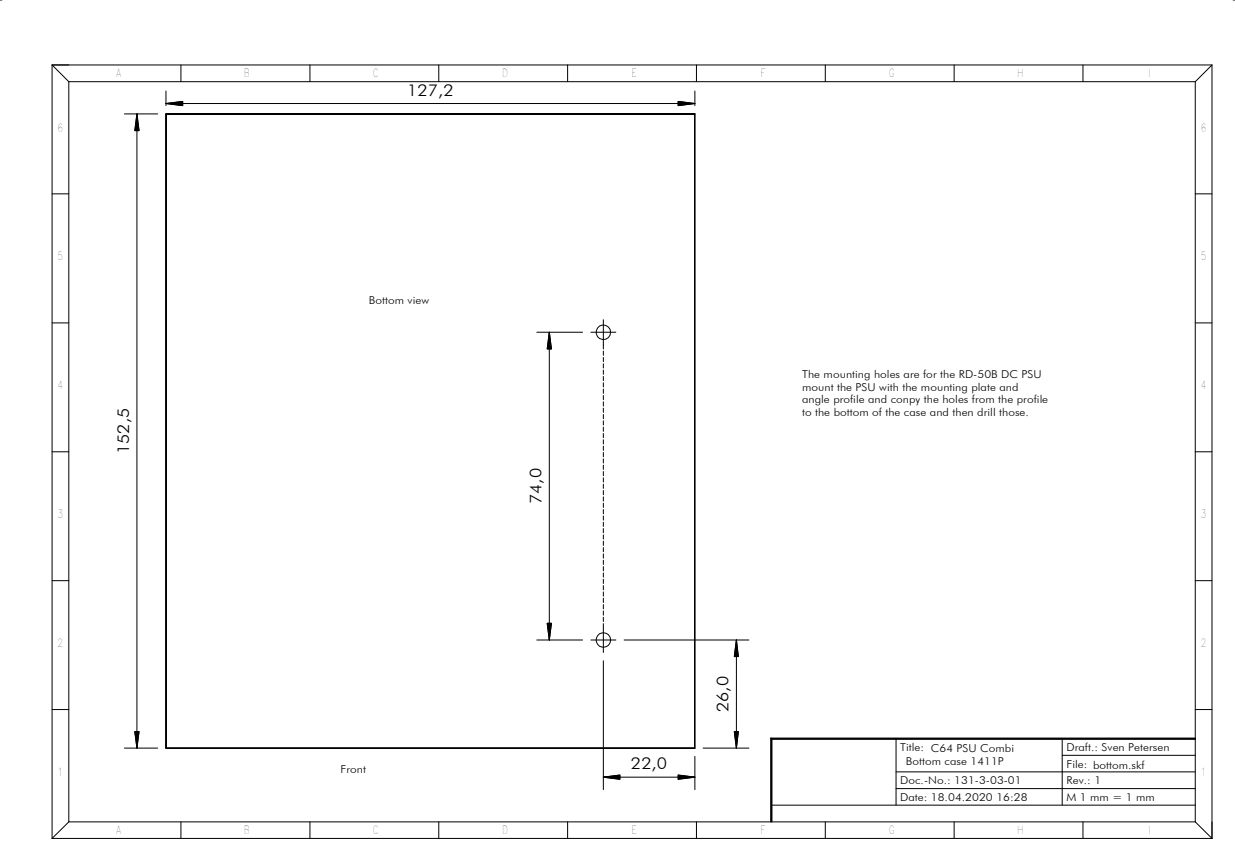
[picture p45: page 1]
Title:; Doc.-No.: 131-3-03-01; Date: 18.04.2020 16:28; C64 PSU Combi; Bottom case 1411P; bottom.skf; Bottom view; Front

The mounting holes are for the RD-50B DC PSU
mount the PSU with the mounting plate and
angle profile and conpy the holes from the profile
to the bottom of the case and then drill those.

Draft.: Sven Petersen
File:
Rev.: 1

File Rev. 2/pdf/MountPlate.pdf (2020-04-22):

99,0

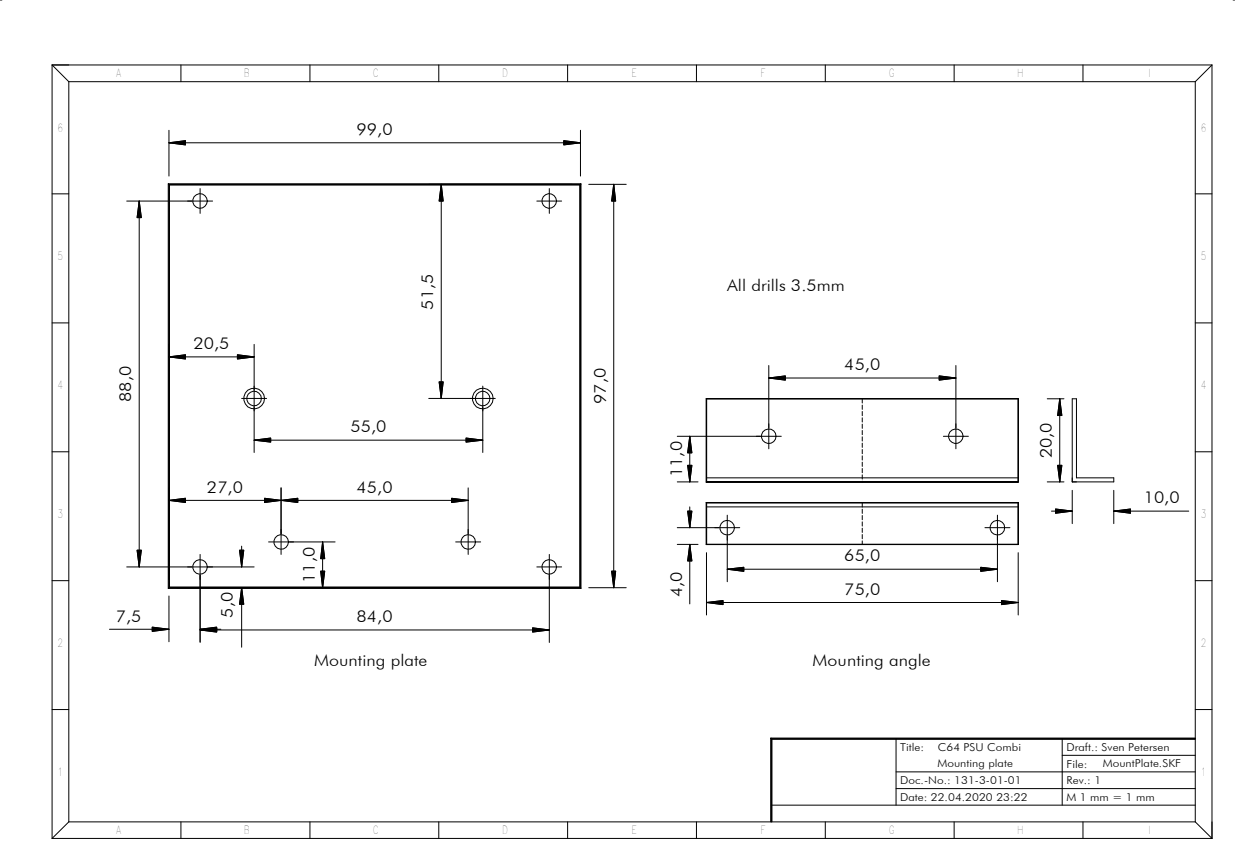
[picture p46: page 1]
Title:; C64 PSU Combi; Mounting plate; MountPlate.SKF 20,0; Mounting angle; All drills 3.5mm

Draft.: Sven Petersen
File:

Doc.-No.: 131-3-01-01 | Rev.: 1
Date: 22.04.2020 23:22 | M 1 mm = 1 mm

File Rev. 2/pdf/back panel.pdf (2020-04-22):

127,8

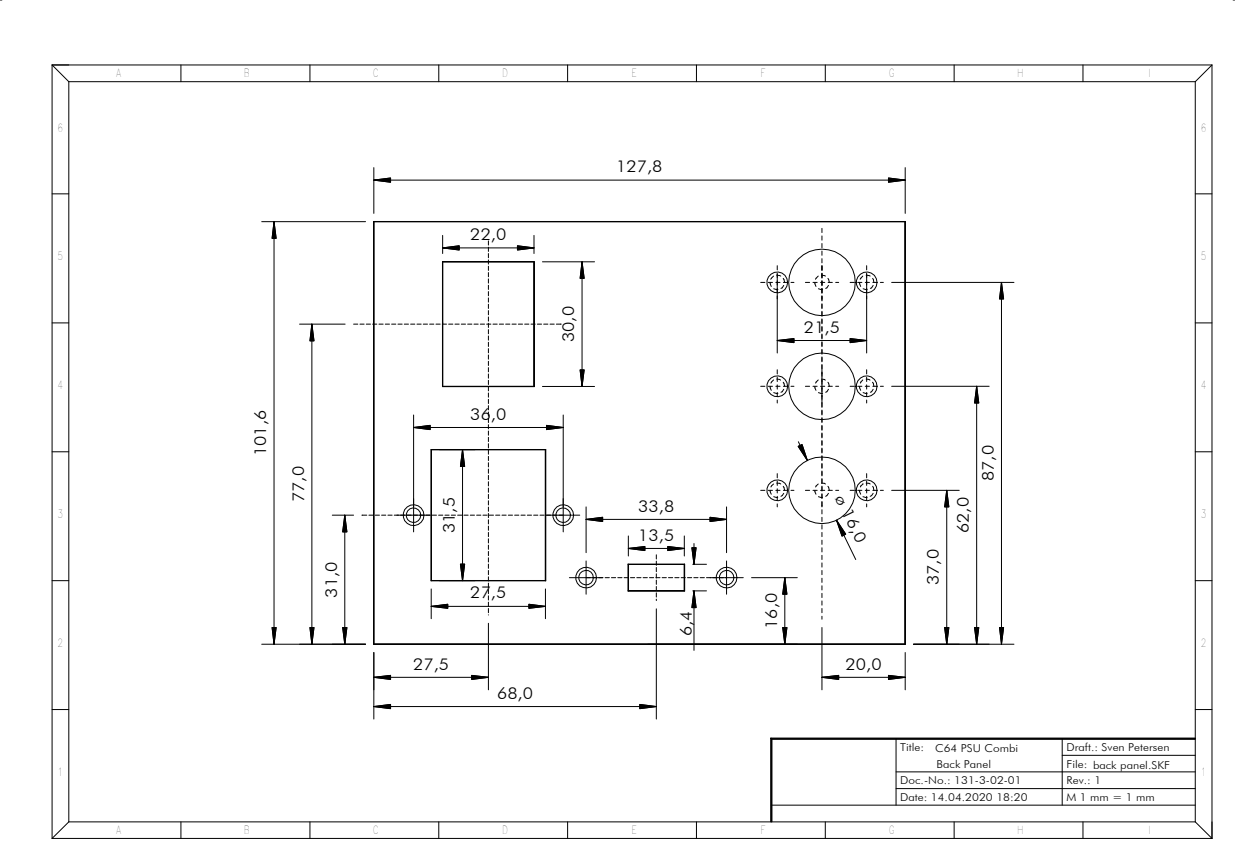
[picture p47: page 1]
Title:; Doc.-No.: 131-3-02-01; Date: 14.04.2020 18:20; C64 PSU Combi; Back Panel; back panel.SKF

Draft.: Sven Petersen
File:
Rev.: 1

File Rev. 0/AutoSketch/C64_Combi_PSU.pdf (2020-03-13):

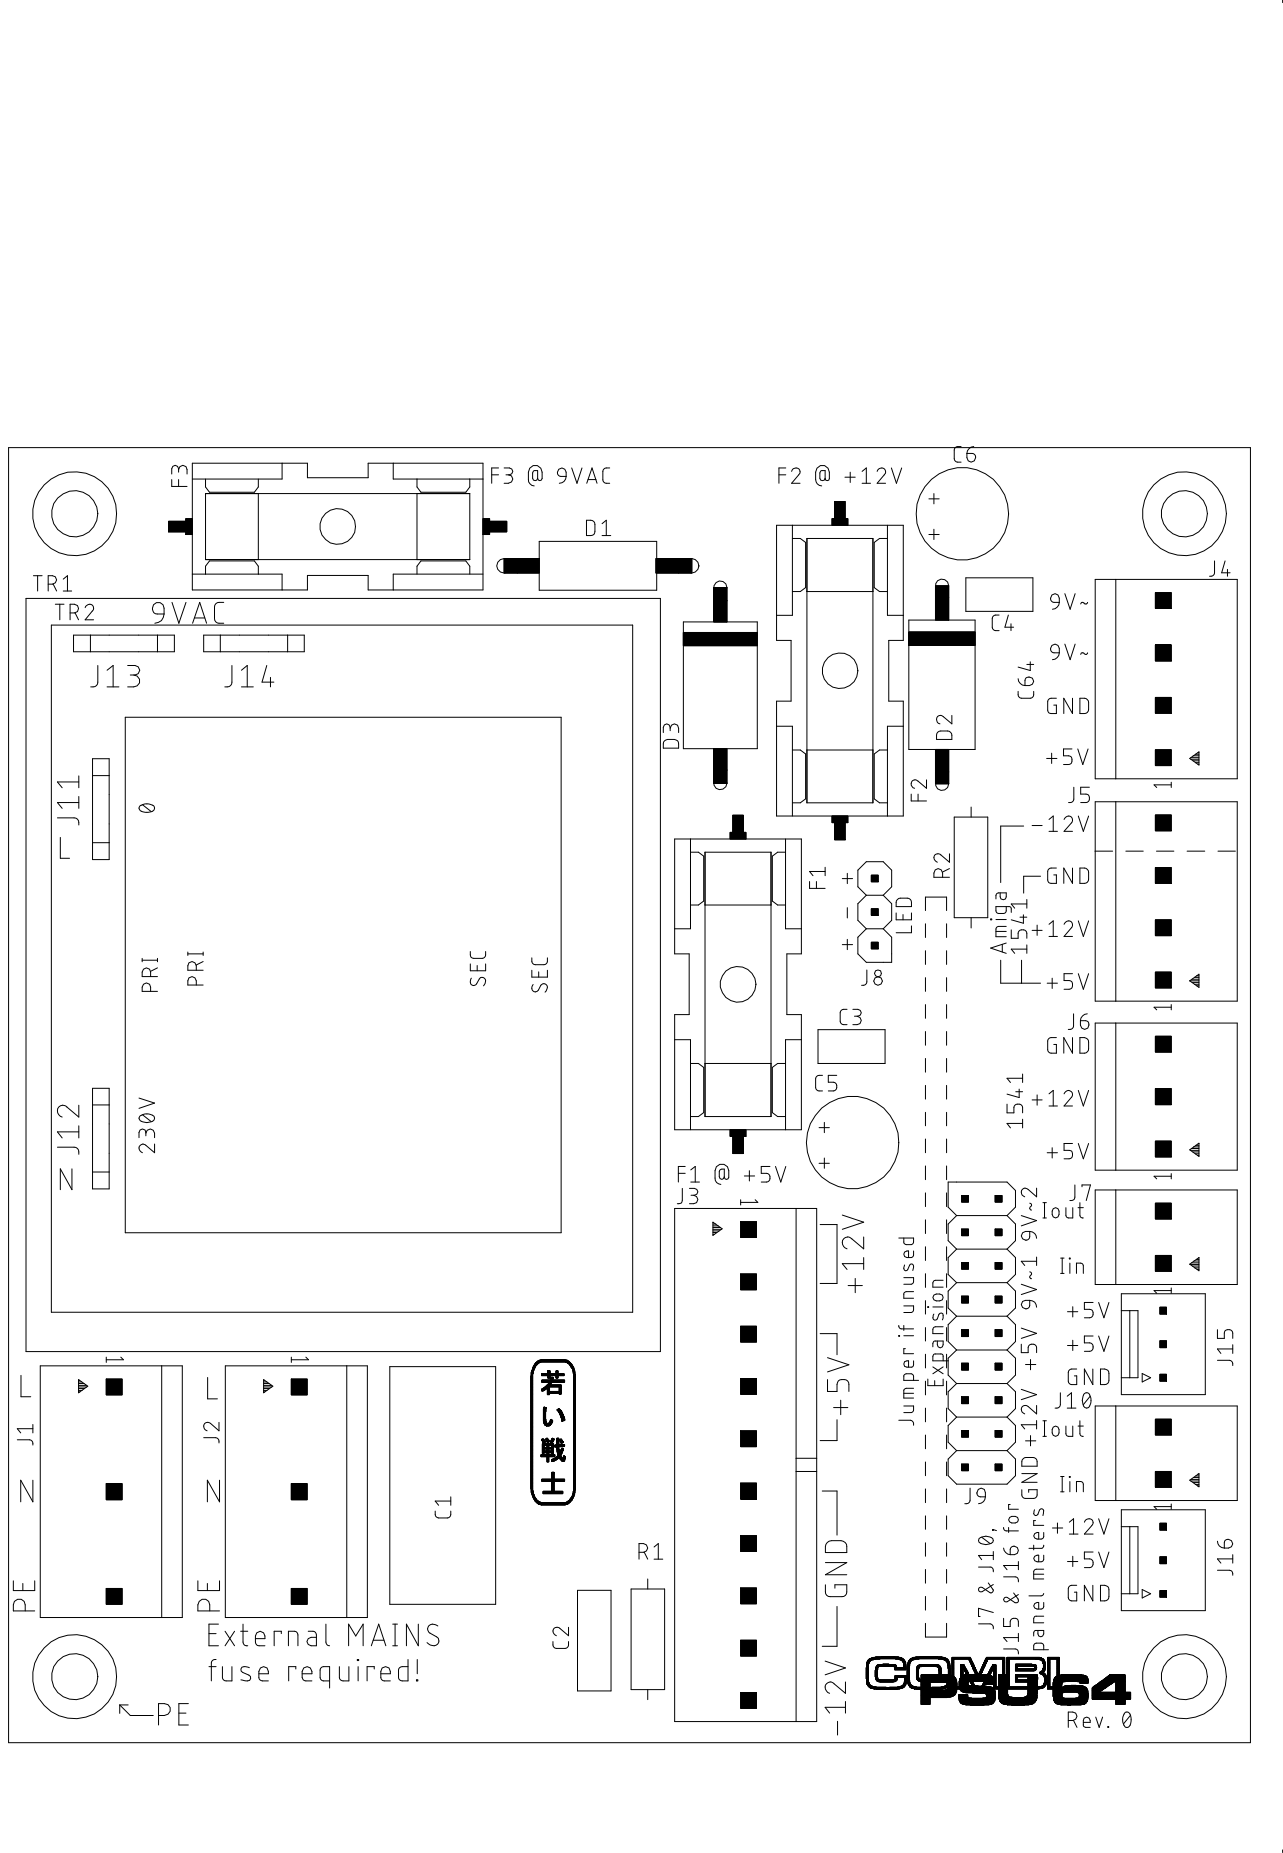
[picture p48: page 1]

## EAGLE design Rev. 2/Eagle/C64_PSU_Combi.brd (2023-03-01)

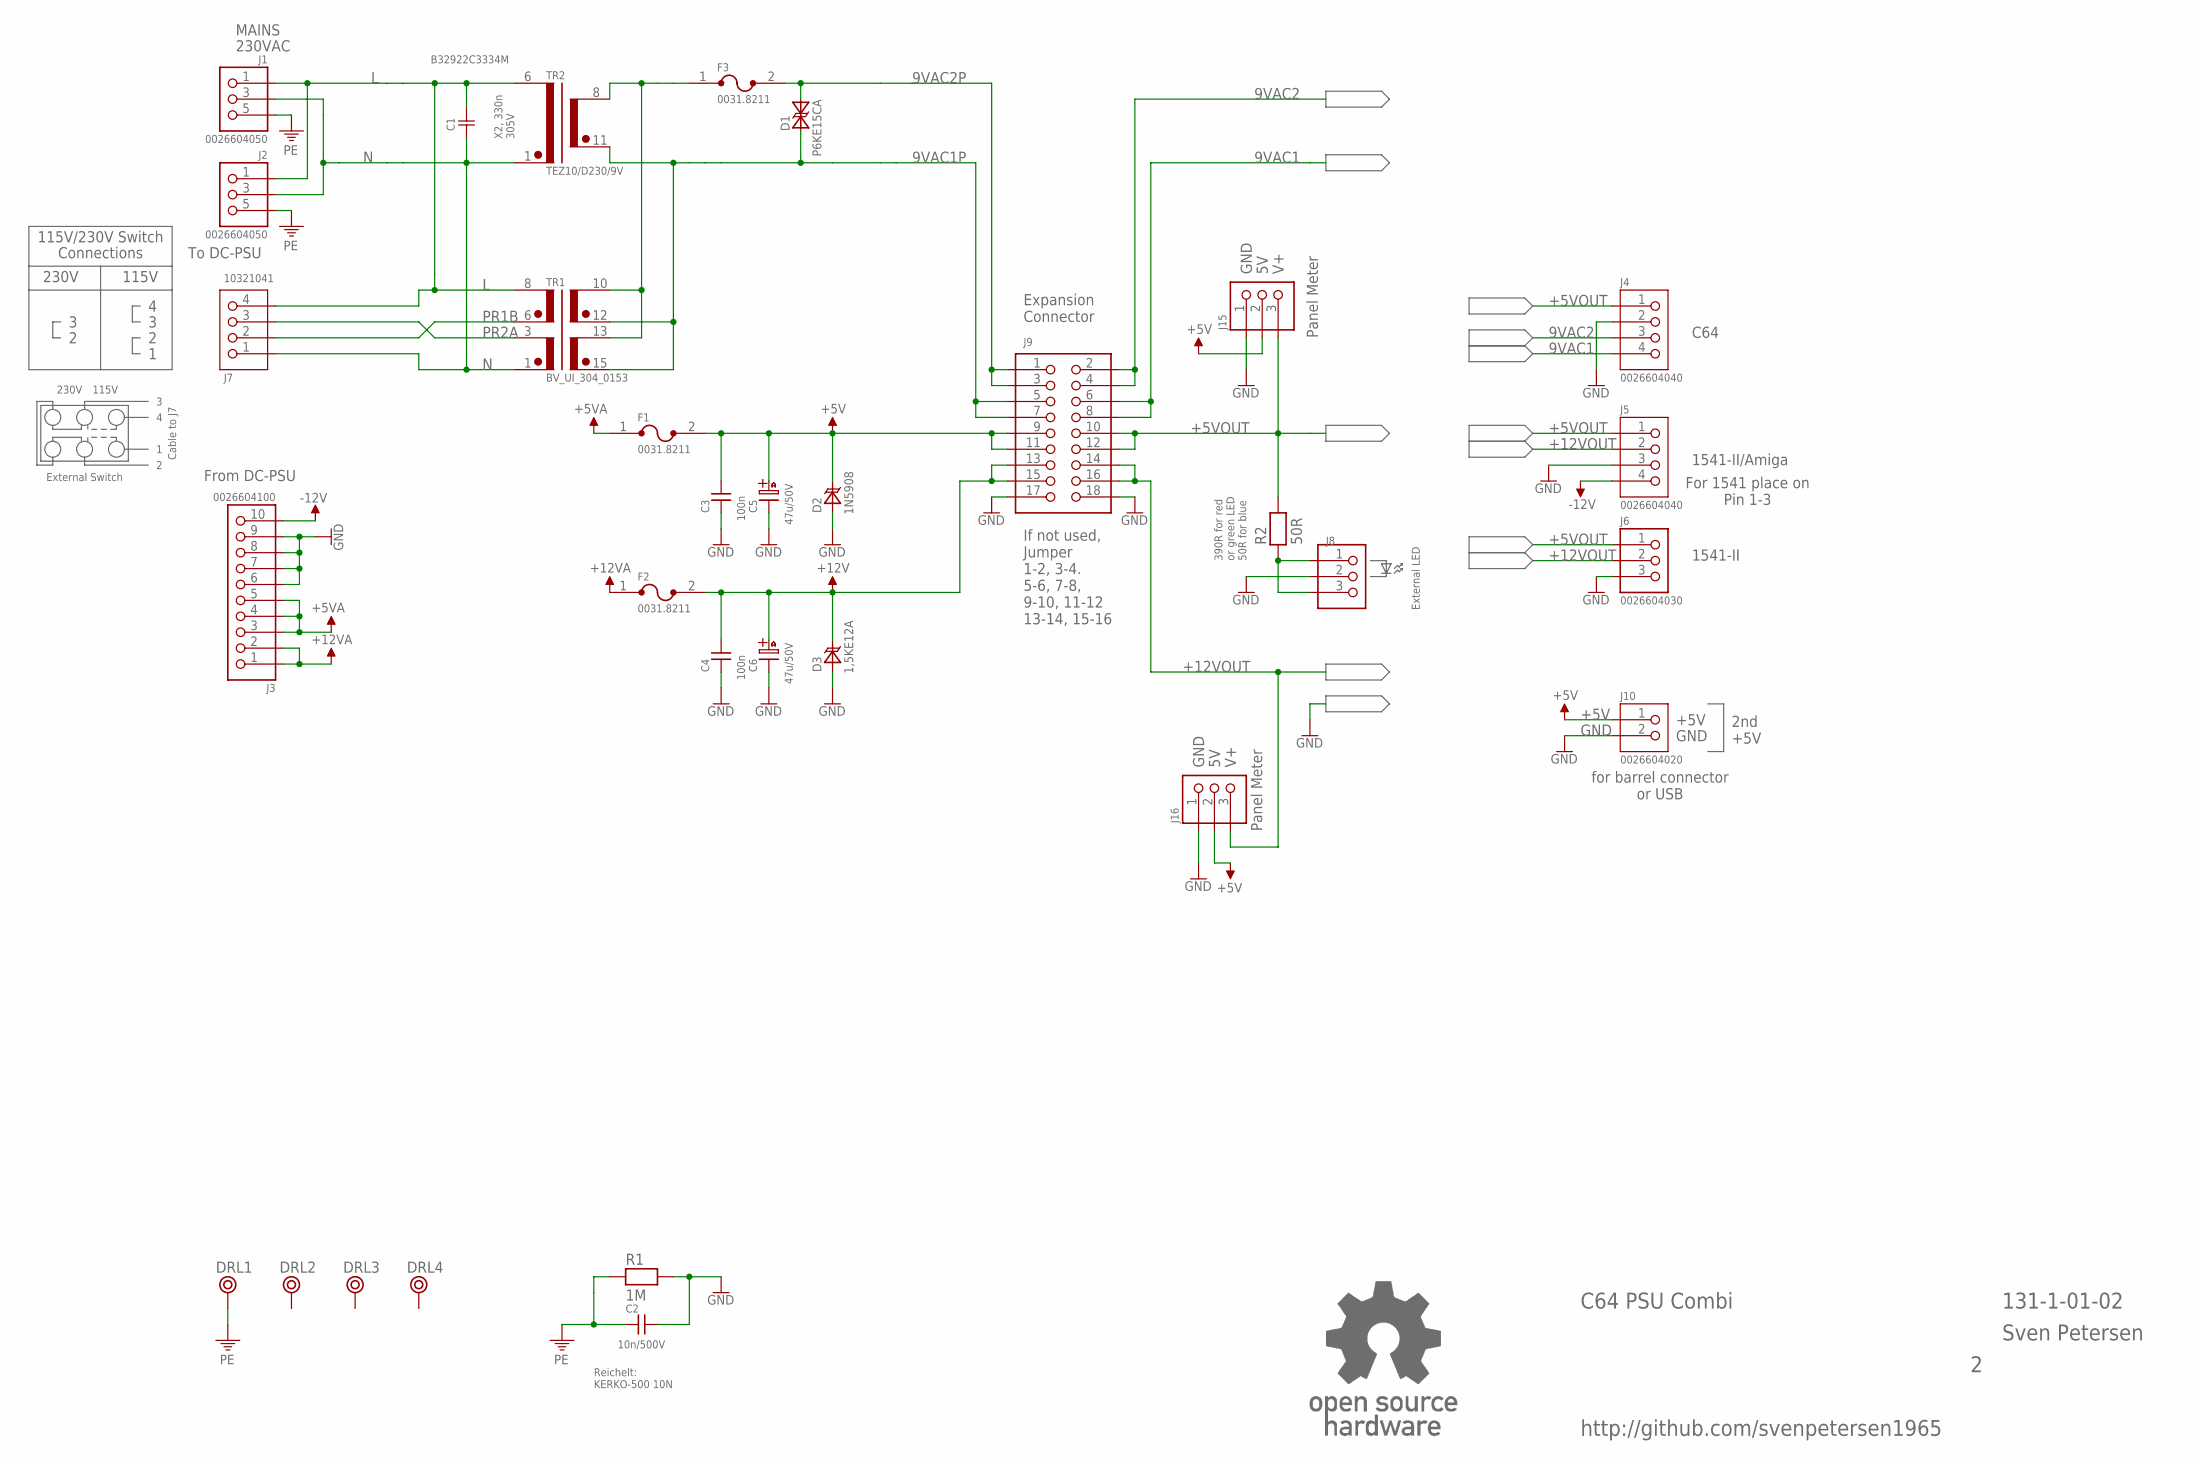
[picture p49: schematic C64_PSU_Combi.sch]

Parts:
C1: B32922C3334M; C-18X8-RM15
C2: 10n/500V; C-5
C3, C4: 100n; C-2,5
C5, C6: 47u/50V; C07/2,5
D1: P6KE15CA; CB417NP
D2: 1N5908; CB429
D3: 1,5KE12A; DO-201
DRL1: BOHR3,5OR; BOHR3,5_OHNE_RESTRICT
DRL2, DRL3, DRL4: BOHR3,5
F1, F2, F3: 0031.8211
J1, J2: 0026604050; SPOX_3.96_5P3
J3: 0026604100; SPOX_3.96_10P
J4, J5: 0026604040; SPOX_3.96_4P
J6: 0026604030; SPOX_3.96_3P
J7: 10321041; SPOX_5.08_4P
J8: PINHD-1X3; 1X03
J9: COMBI-9X2P; COMBI-9X2
J10: 0026604020; SPOX_3.96_2P
J15, J16: 6410-3P
R1: 1M; R-10
R2: 50R; R-10
TR1: BV_UI_304_0153; UI30
TR2: TEZ10/D230/9V; TEZ10
U$31: OPEN_SOURCE_HW; OPENHW

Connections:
9VAC1: J4.4, J9.6, J9.8
9VAC1P: D1.A (A1), J9.5, J9.7, TR1.12 (SEC1B), TR1.15 (SEC2B), TR2.11 (SEC12)
9VAC2: J4.3, J9.2, J9.4
9VAC2F: F3.1, TR1.10 (SEC1A), TR1.13 (SEC2A), TR2.8 (SEC11)
9VAC2P: D1.K (A2), F3.2, J9.1, J9.3
+5V: C3.2, C5.A (+), D2.K, F1.2, J9.9, J9.11, J10.1, J15.2, J16.2
+5VA: F1.1, J3.3, J3.4, J3.5
+5VOUT: J4.1, J5.1, J6.1, J9.10, J9.12, J15.3, R2.2
+12V: C4.2, C6.A (+), D3.K, F2.2, J9.13, J9.15
+12VA: F2.1, J3.1, J3.2
+12VOUT: J5.2, J6.2, J9.14, J9.16, J16.3
-12V: J3.10, J5.4
GND: C2.2, C3.1, C4.1, C5.K (-), C6.K (-), D2.A, D3.A, J3.6, J3.7, J3.8, J3.9, J4.2, J5.3, J6.3, J8.2, J9.17, J9.18, J10.2, J15.1, J16.1, R1.2
L: C1.2, J1.1, J2.1, J7.4, TR1.8 (PRI1A), TR2.6 (PRI1)
N: C1.1, J1.3 (2), J2.3 (2), J7.1, TR1.1 (PRI2B), TR2.1 (PRI2)
unnamed: J8.1, J8.3, R2.1
PE: C2.1, DRL1.P$1, J1.5 (3), J2.5 (3), R1.1
PR1B: J7.2, TR1.6 (PRI1B)
PR2A: J7.3, TR1.3 (PRI2A)

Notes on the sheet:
230VAC
X2, 330n 305V
External LED
390R for red or green LED 50R for blue
Reichelt: KERKO-500 10N
Expansion Connector
If not used, Jumper 1-2, 3-4. 5-6, 7-8, 9-10, 11-12 13-14, 15-16
GND
Panel Meter
MAINS
From DC-PSU
C64
1541-II/Amiga
1541-II
C64 PSU Combi
131-1-01-02
Sven Petersen
To DC-PSU
For 1541 place on Pin 1-3
115V/230V Switch
230V
115V
Connections
Cable to J7
External Switch
http://github.com/svenpetersen1965
+5V
2nd +5V
for barrel connector or USB

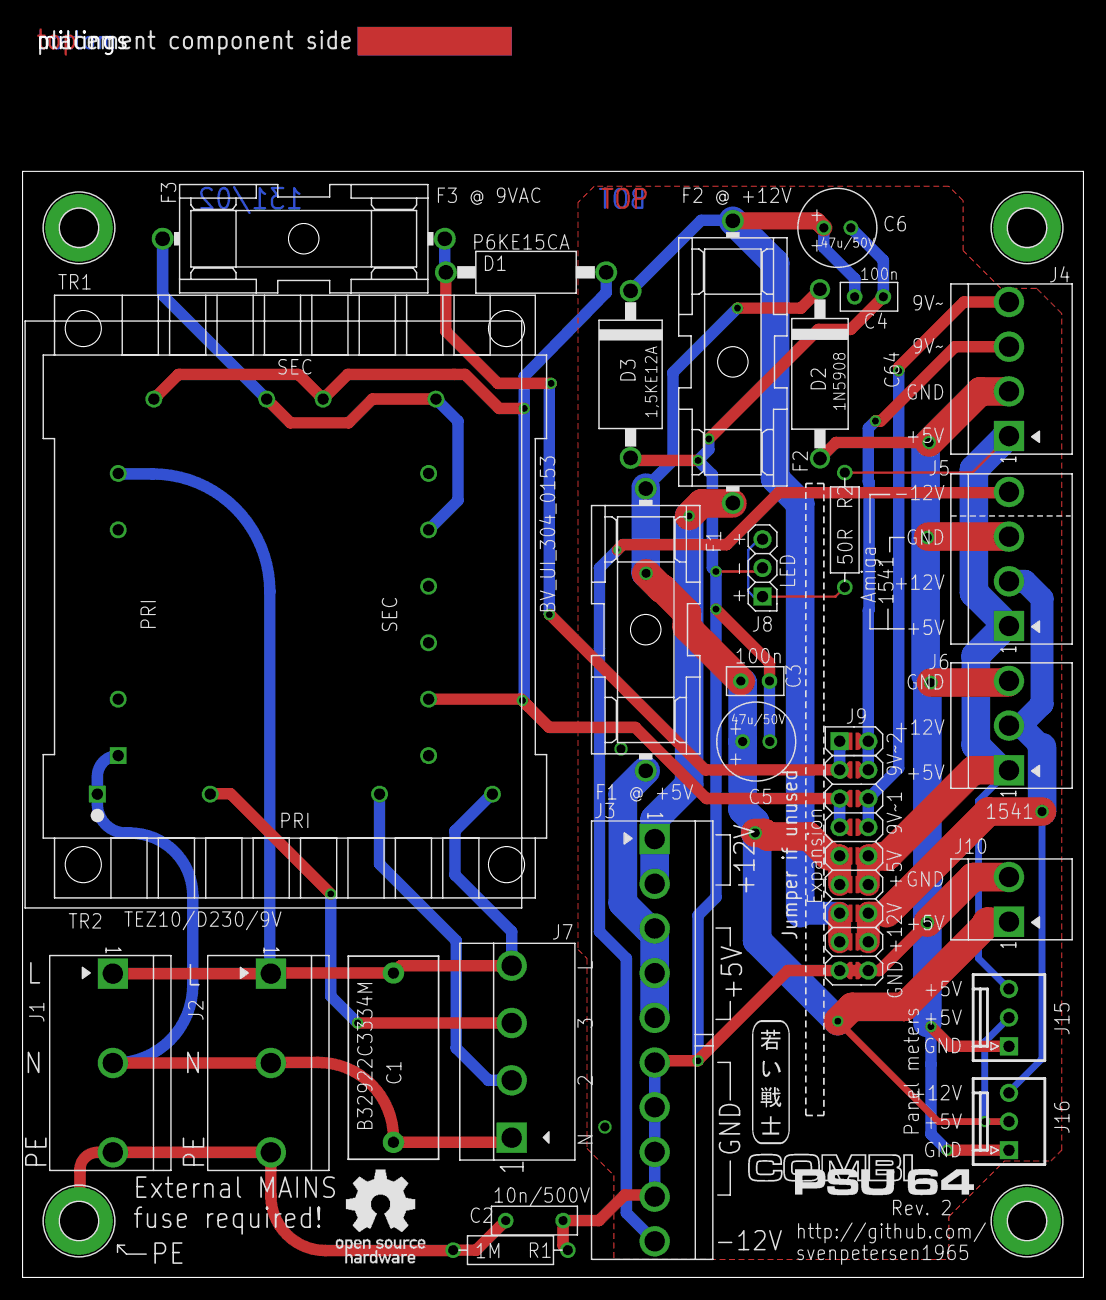
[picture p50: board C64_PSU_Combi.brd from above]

Board: 2 copper layers, 94.0 x 98.0 mm, 37 parts (0 on the bottom side), 19 nets.

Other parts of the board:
U$43: SVEN_TAG
U$44: PCB-TITLE/
U$45: 2LAYER
U$49: COMBIPSU64

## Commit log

2020-03-13 Initial upload
    [C64_CombiPSU_BOM_v0_0.xlsx, C64_Combi_PSU.brd, C64_Combi_PSU.dxf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]
2020-04-22 Rev. 1 released
    [C64_CombiPSU_BOM_v1_0.xlsx, C64_PSU_Combi.brd, C64_PSU_Combi.dxf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]
2020-08-08 Silk Screen Update
    [C64_PSU_Combi.brd, C64_PSU_Combi.sch]
2023-03-01 Rev. 2 released
    [C64_CombiPSU_BOM_v2_0.xlsx, C64_PSU_Combi.brd, C64_PSU_Combi.dxf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]
